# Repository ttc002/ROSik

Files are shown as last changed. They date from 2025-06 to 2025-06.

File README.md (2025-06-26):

# ROSiK  
**Robot Operating System — interactive Kit**  

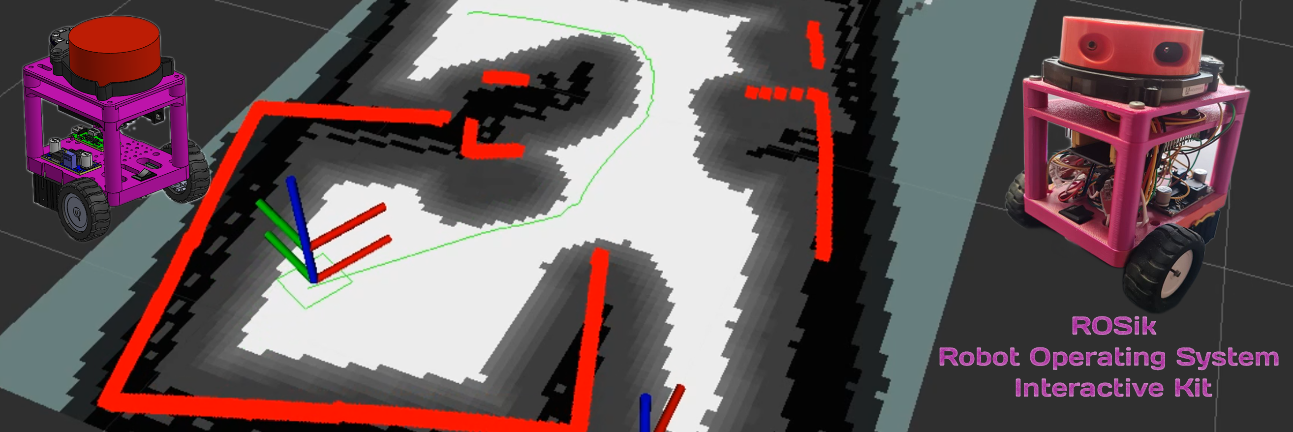
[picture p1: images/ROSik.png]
Робот ROSik


Мини-робот на **ESP32 Wroom-32 + ROS 2**, который:
* транслирует одометрию и лидар по Wi-Fi через WebSocket-мост;
* строит карты и локализуется (`slam_toolbox`);
* планирует путь (`nav2`);
* легко расширяется модулями — камера, IMU, динамик, адресные LED, OLED-дисплей.

Работает **на любой машине**: чистая Ubuntu 24.04, WSL 2 под Windows или виртуалка — нужен лишь Wi-Fi.

Инструкция по установке [Ubuntu](https://stepik.org/lesson/1505338/step/1?unit=1525484), [WSL](https://stepik.org/lesson/1505339/step/4?unit=1525485), а также  [запуску графический приложений (RVIZ)](https://stepik.org/lesson/1505339/step/5?unit=1525485).

---

## 📑 Содержание
1. [Аппаратная часть (BOM)](#аппаратная-часть-bom)  
2. [Электрическая схема](#электрическая-схема)  
3. [3D-модели и сборка](#3d-модели-и-сборка)  
4. [Прошивка ESP32](#прошивка-esp32)
5. [Настройка PID и тестирование](#настройка-pid)
6. [Установка нод в ROS2](#установка-по-на-пк)  
7. [Запуск ROS 2-нод](#запуск-ros-2-нод)  
8. [Контакты](#контакты)

## 🛒<a id="аппаратная-часть-bom">Аппаратная часть (BOM)</a>

* | 1 | **ESP32 Wroom-32 DevKit**         | https://aliexpress.ru/item/1005006697750568.html
* | 2 | DC-мотор N20 60 RPM + энкодер     | https://aliexpress.ru/item/1005007145668771.html
* | 3 | Драйвер моторов ZK-5AD            | https://aliexpress.ru/item/1005005798367960.html
* | 4 | Лидар                             | https://aliexpress.ru/item/1005008371059417.html
* | 5 | Аккумулятор 18650 × 2 + держатель | https://aliexpress.ru/item/1005005447141518.html
* | 6 | Понижающий DC-DC                  | https://aliexpress.ru/item/32896699470.html
* | 7 | Переключатель питания             | https://aliexpress.ru/item/4000973563250.html
* | 8 | Type-C зарядка  2S 1A             | https://aliexpress.ru/item/1005006628986640.html

---

## 🔌 <a id="электрическая-схема">Электрическая схема</a>

Файл CorelDraw **`/Scheme/ROSik_scheme.cdr`**  
а также PNG **`/Scheme/scheme.png`**. 
В схеме показаны соединения питания (8,4 V → 5 V), сигнальные линии к драйверу моторов, энкодерам, лидару (UART)  
схема Fritzing **`/Scheme/MAIN.png`** с добавлением дисплеев и динамика.
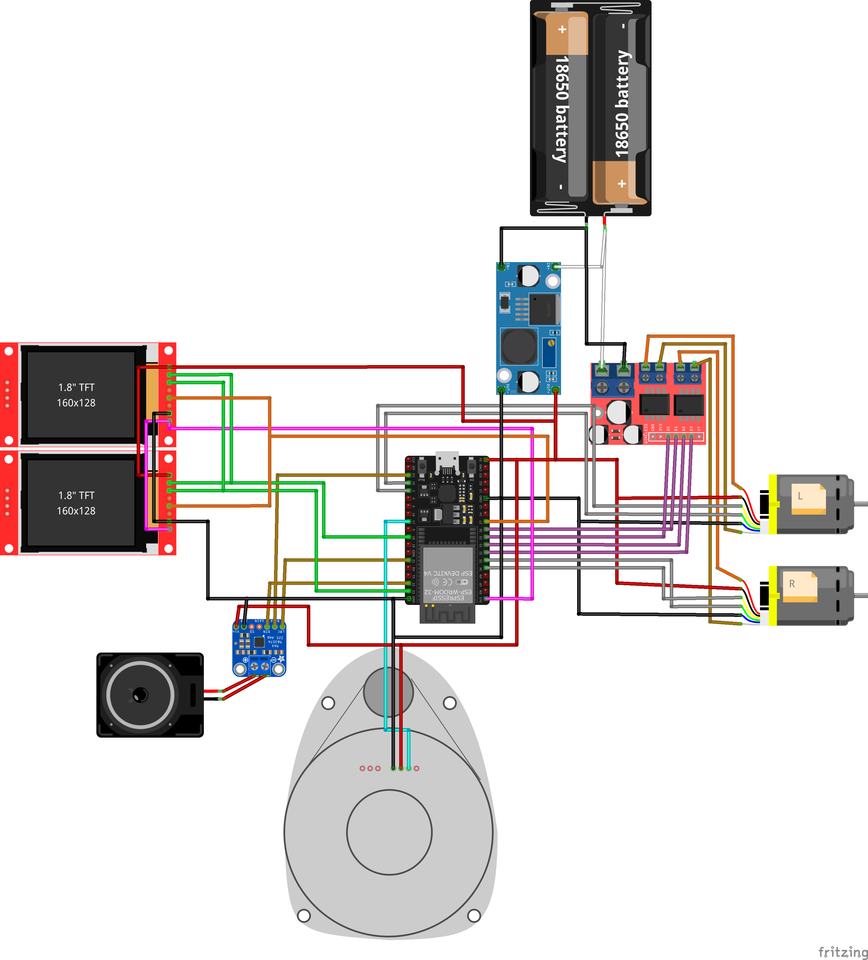
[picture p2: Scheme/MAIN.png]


---

## 🖨 <a id="3d-модели-и-сборка">3D-модели и сборка</a>

Каталог **`/3D`** содержит файлы SolidWorks (`.SLDPRT/.SLDASM`) и готовые `.STL` для печати.

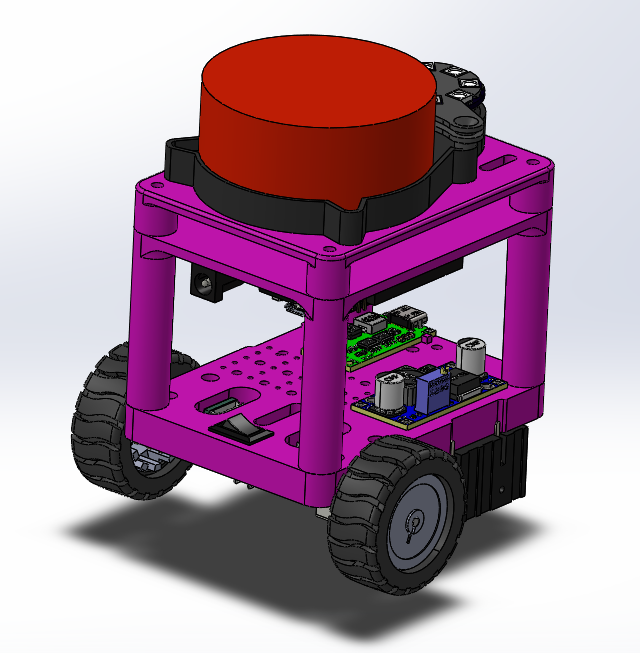
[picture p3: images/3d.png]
3D-модель

* | `00 - WheelLayer.*`    | Нижняя плита с моторами 
* | `01 - LidarLayer.*`    | Верхняя плита под лидар 
* | `10 - ESPLayer.*`      | Средняя плита под ESP32 и драйвер 
* | `Bracket.* / Holder.*` | Крепёж моторов, DC-DC и т.п. 
* | `RosikAssambl.SLDASM`  | Полная сборка 
* | `STL/`                 | Файлы для печати (0,2 мм, PLA) 
* | `ROSik.png`            | Рендер итогового вида 

Собирать снизу → вверх, фиксируя слои стойками M3 × 20 мм. Проводку прячем во внутреннем объеме робота.

---

## 🔥<a id="прошивка-esp32"> Прошивка ESP32 </a>

### Требуемые библиотеки (Arduino IDE)

* Скопируйте ZIP-файлы из `/esp32_libraries/` в `Documents/Arduino/libraries`  
* Добавьте плату ESP32: `File → Preferences → Additional URL` → `https://raw.githubusercontent.com/espressif/arduino-esp32/gh-pages/package_esp32_index.json`
* Через Board Manager добавьте ESP32

### Шаги прошивки

1. Откройте **`/esp32_firmware/esp32_firmware.ino`** в Arduino IDE.  
2. Измените SSID и пароль Wi-Fi сети.  
3. Порт: `Tools → Port → /dev/ttyUSB?` (или COM\*)
4. Плата: `ESP32 Wroom DA Module`
5. Загрузка `Ctrl + U`.  
6. После рестарта ESP32 печатает IP-адрес в Serial Monitor. Скорость: `115200 baud`.

> Прошивка для ESP32_cam (`/esp32_cam/firmware/firmware.ino`) 

---

## <a id="настройка-pid">Настройка PID и тестирование робота</a>

### Утилита позволив вам подобрать коэффициенты PID - регулятора и приверить его работу
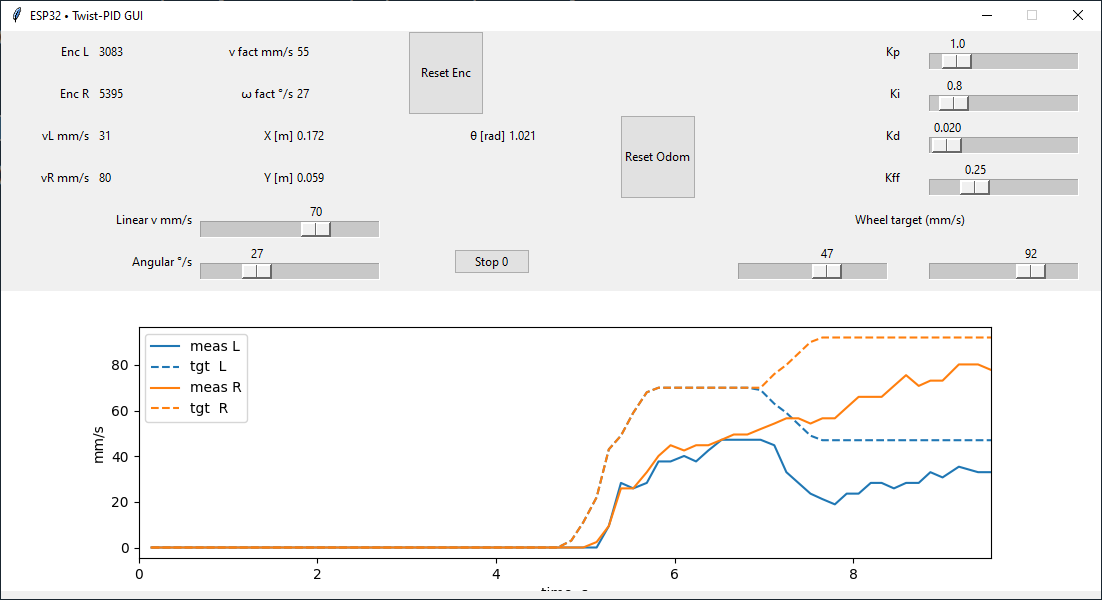
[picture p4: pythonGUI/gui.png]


* Измените IP адрес
* Проверьте работу одометрии и управления роботом
* Подберите коэффициенты и измените их в прошивке робота

---

## 🐧 Установка Ноды в ROS2

```bash
# 1. Создаём рабочую директорию
mkdir -p ~/ros2_ws/src && cd ~/ros2_ws/src

# 2. Копируем esp32_bridge в ~/ros2_ws/src

# 3. Сборка
cd ~/ros2_ws
colcon build
source install/setup.bash

````

* Все конфиги лежат в директории `esp32_bridge\config`. При запуске исправить пути к конфигам на актуальные
* протестировано на **ROS 2 Jazzy** (Ubuntu 24.04)
* в **WSL 2** нужен X-server (XLaunch) для RViz 2

---

## 🚀<a id="запуск-ros-2-нод"> Запуск ROS 2-нод </a>

| Шаг | Команда | Описание |
| --- | --- | --- |
| 1 | `ros2 run esp32_bridge esp32_bridge --ros-args -p host:=<IP_ESP32> ` | WebSocket-мост |
| 2 | `rviz2`  → `File → Open Config` → `config/rviz/rosik.rviz` | Визуализация данных |
| 3 | `ros2 launch slam_toolbox online_sync_launch.py slam_params_file:=~/ros2_ws/src/esp32_bridge/config/slam_param.yaml` | Онлайн SLAM |
| 4 | `ros2 run teleop_twist_keyboard teleop_twist_keyboard` | Телеуправление |
| 5 | `ros2 service call /slam_toolbox/serialize_map slam_toolbox/srv/SerializePoseGraph "{filename: '~/ros2_ws/maps/my_map'}"` | Сохранить карту |
| 6 | `ros2 launch slam_toolbox localization_launch.py slam_params_file:=~/ros2_ws/src/esp32_bridge/config/slam_localization.yaml`| Локализация |
| 7 | `ros2 launch nav2_bringup navigation_launch.py params_file:=~/ros2_ws/src/esp32_bridge/config/nav_param.yaml` | Навигация `nav2` |

> **WSL 2**: перед запуском RViz 2<br>
> `export DISPLAY=$(ip route | awk '/default/ {print $3}'):0.0` или
> `export DISPLAY=xxx.xxx.xxx.xxx:0.0`

Настройки RVIZ в файле `esp32_bridge/config/rviz.rviz`
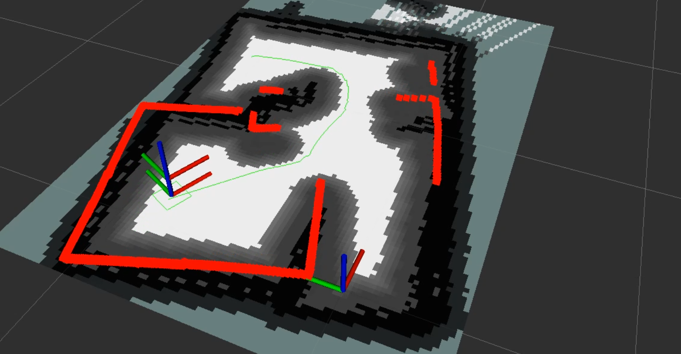
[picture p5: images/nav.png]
Работа навигации


## GIF - демонстрация движения в автономном режиме
Работа навигации

## Дисплей
`ros2 run image_stream send_image --ros-args -p host:=<YOUR_ESP_IP>` - отправляет данные по socket на дисплей из /image_raw. Прошивка MAIN.ino

`ros2 run image_stream read_image --ros-args -p video_path:=<VIDEO_PATH>` - отправляет данные в топик /image_rgb

## Динамик 
`ros2 run esp_miniBot send_music --ros-args -p host:=<YOUR_ESP_IP>` - отправляет музыку из топика /audio_bytes

`ros2 run esp_miniBot read_mp3 --ros-args -p folder:=<YOUR_FOLDER>` - чтение mp3 из папки

`ros2 run esp_miniBot speaker` - создание вируального динамика, и чтение из него в топик

---
<a id="контакты">Контакты</a>
* Telegram: **[@burmistrov\_robotics](https://t.me/burmistrov_robotics)**  **[@petrArchLinux](https://t.me/petrArchLinux)**
* Stepik- Народный курс по ROS2: [https://stepik.org/course/221157](https://stepik.org/course/221157)

---

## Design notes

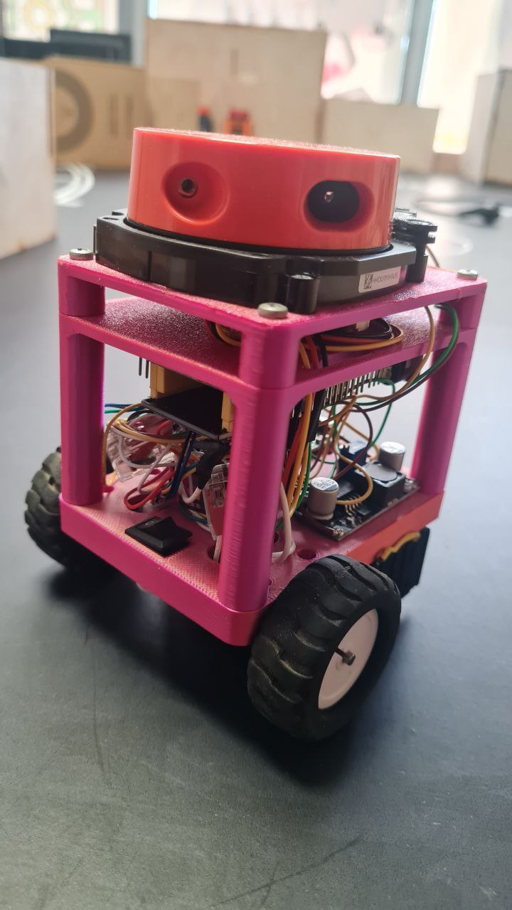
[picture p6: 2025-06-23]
images/photo.jpg

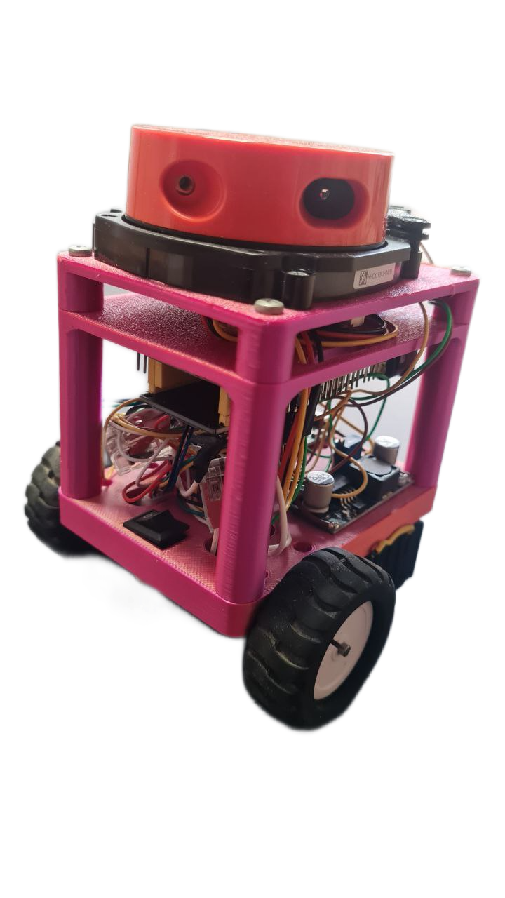
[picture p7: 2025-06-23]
images/photo.png

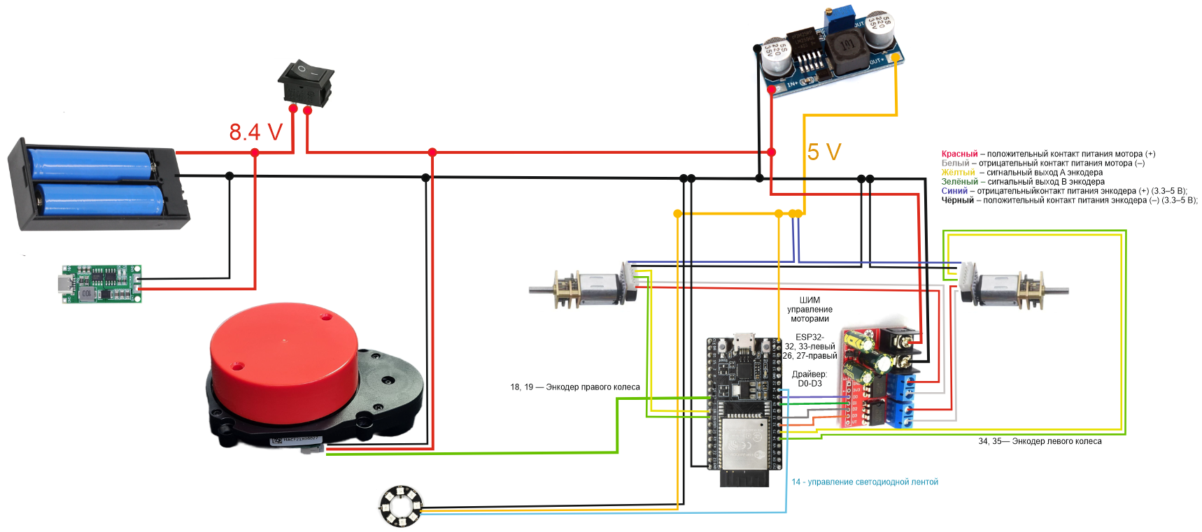
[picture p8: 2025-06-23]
Scheme/scheme.png

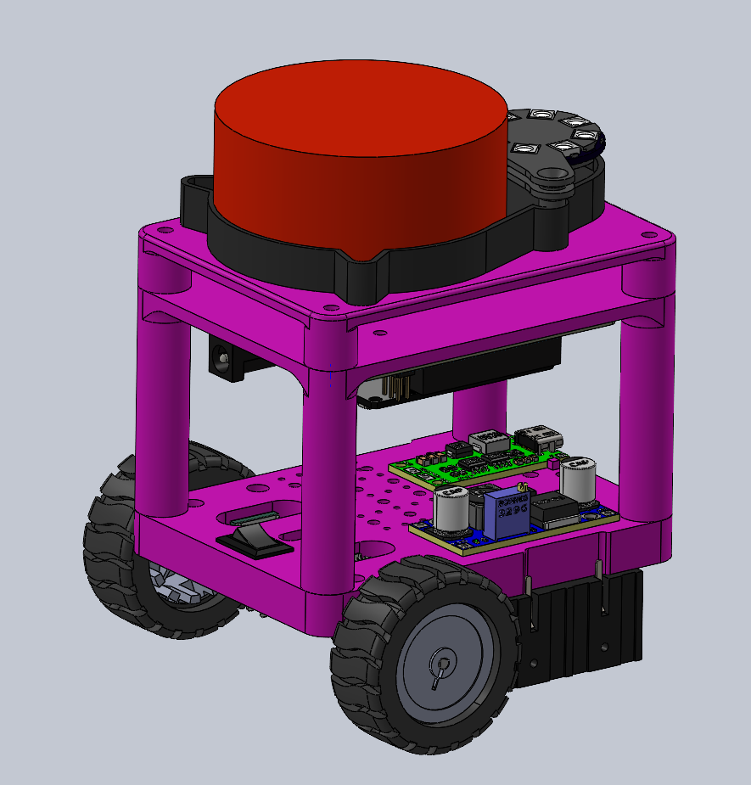
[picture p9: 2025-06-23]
3D/ROSik.png

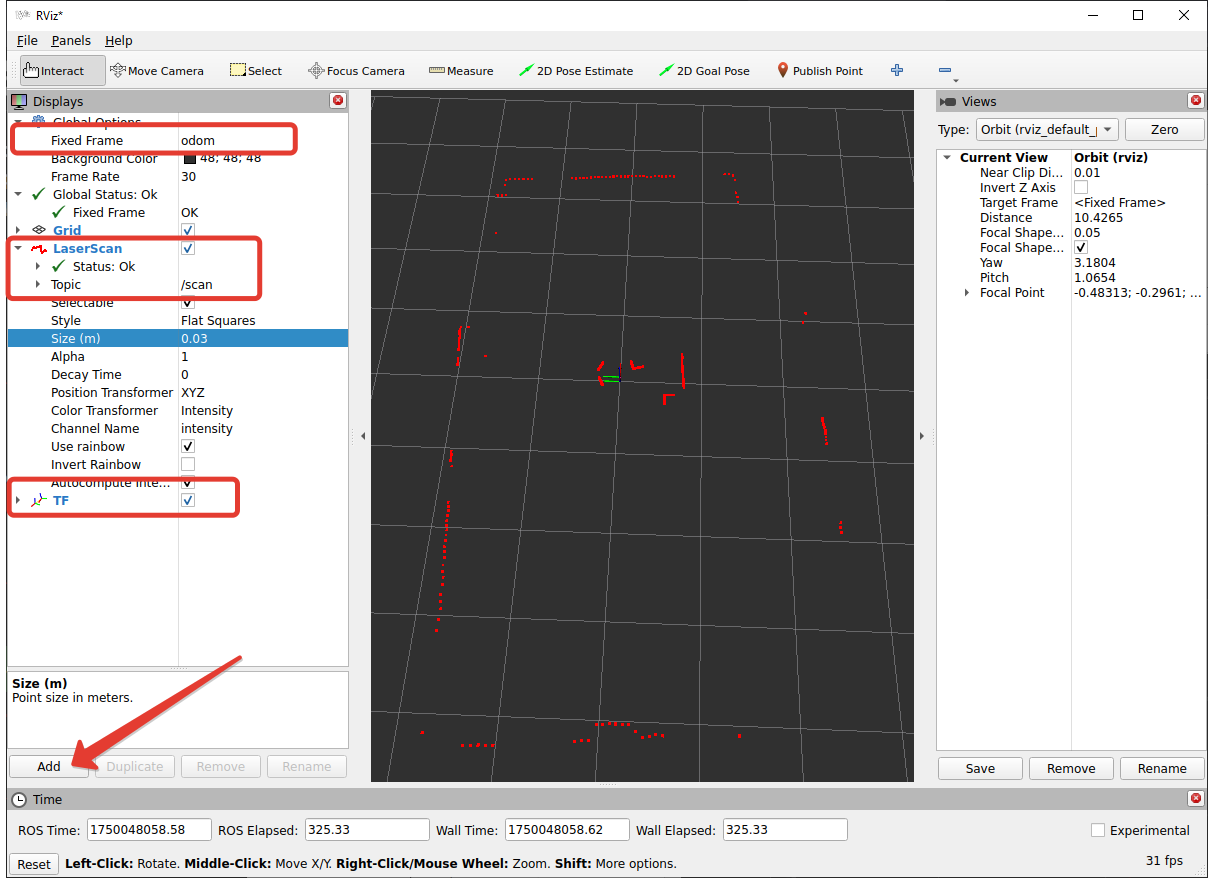
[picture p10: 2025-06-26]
code/rviz2.png

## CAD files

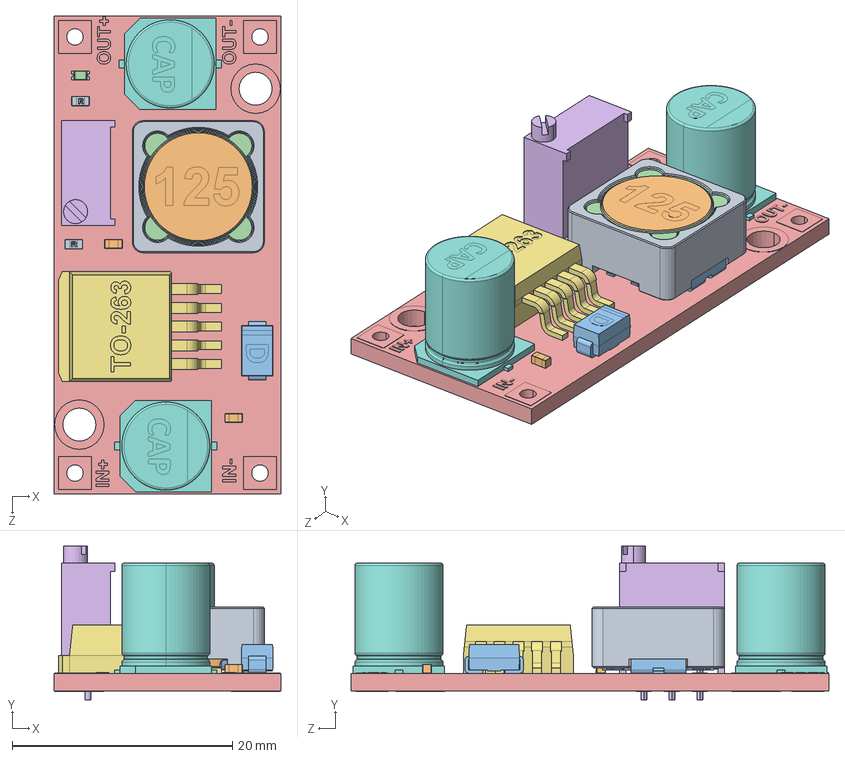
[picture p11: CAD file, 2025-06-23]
3D/DC_DC.SLDASM
20.6 x 14.0 x 43.4 mm
001^CDRH125_HW-411.STEP
002^CDRH125_HW-411.STEP
005^CDRH125_HW-411.STEP x 2
003^CDRH125_HW-411.STEP
Board^HW-411.STEP
RES_3296W^HW-411.STEP
TO-263-5^HW-411.STEP
CAP_SMD_AL_08.0x10.0^HW-411.STEP x 2
RES_SMD_0603^HW-411.STEP x 2
CAP_SMD_0603_H0.50^HW-411.STEP x 2
Diode_DO214AC(SMA)^HW-411.STEP
LED_0603_Green^HW-411.STEP

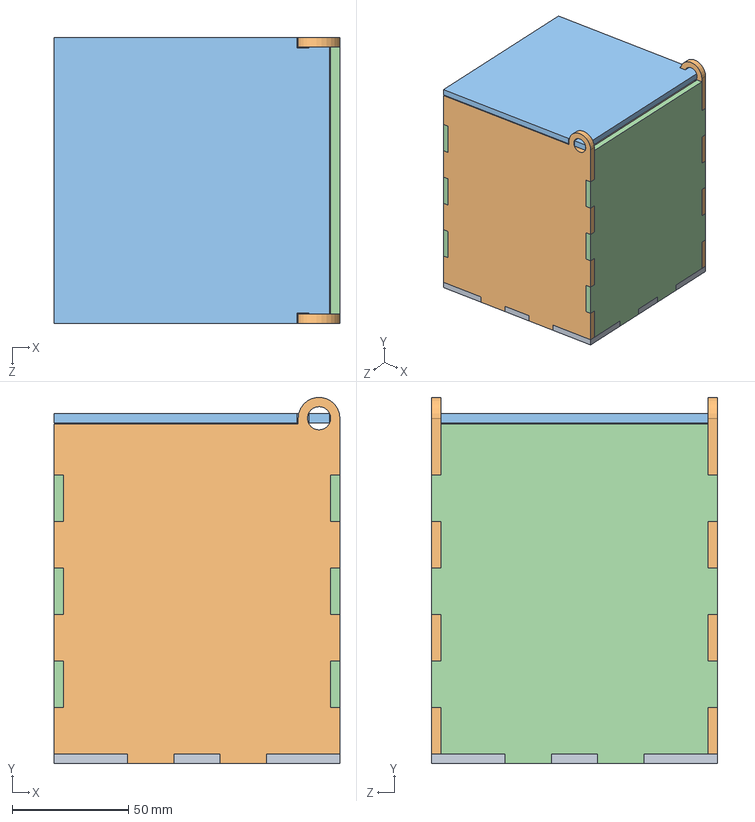
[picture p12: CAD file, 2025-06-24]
3D/ROSik_BOX/Сборка122.SLDASM
123.0 x 157.4 x 123.0 mm
Дно
БокСОтв x 2
Крышка
ПередСтенка x 2

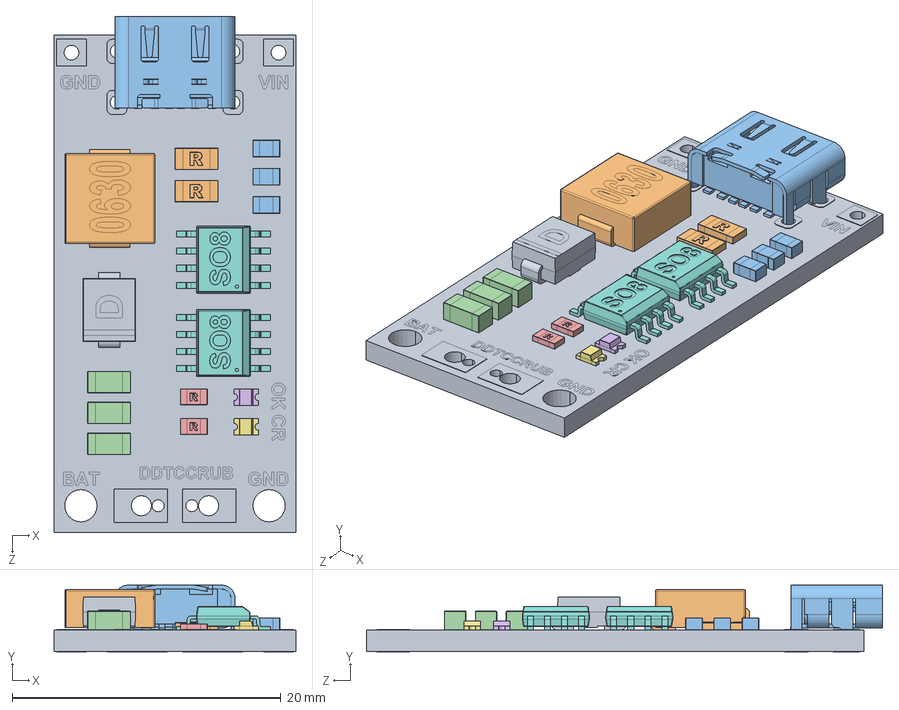
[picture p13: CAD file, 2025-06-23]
3D/Type_cCharger.SLDASM
18.0 x 4.98 x 38.4 mm
Board^DDTCCRUB CN330X.STEP
RES_SMD_1206^DDTCCRUB CN330X.STEP x 2
CAP_SMD_0805_H0.9^DDTCCRUB CN330X.STEP x 3
CAP_SMD_1206_H1.4^DDTCCRUB CN330X.STEP x 3
RES_SMD_0805^DDTCCRUB CN330X.STEP x 2
LED_0805_Green^DDTCCRUB CN330X.STEP
LED_0805_Red^DDTCCRUB CN330X.STEP
SO8^DDTCCRUB CN330X.STEP x 2
Diode_DO214AA(SMB)^DDTCCRUB CN330X.STEP
Inductor_SMD_AMPLF_0630^DDTCCRUB CN330X.STEP
USB_Type-C_Female_6pin^DDTCCRUB CN330X.STEP

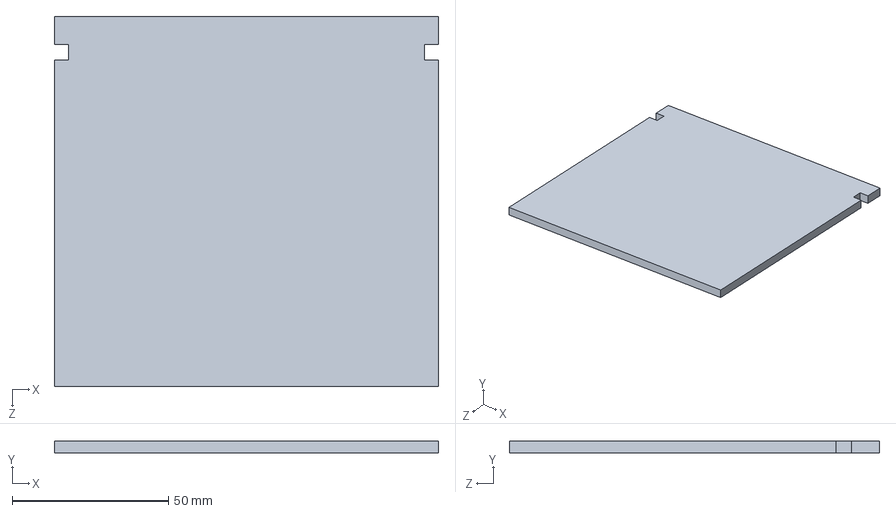
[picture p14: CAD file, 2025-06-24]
3D/ROSik_BOX/Крышка.SLDPRT
123.0 x 4.00 x 118.5 mm

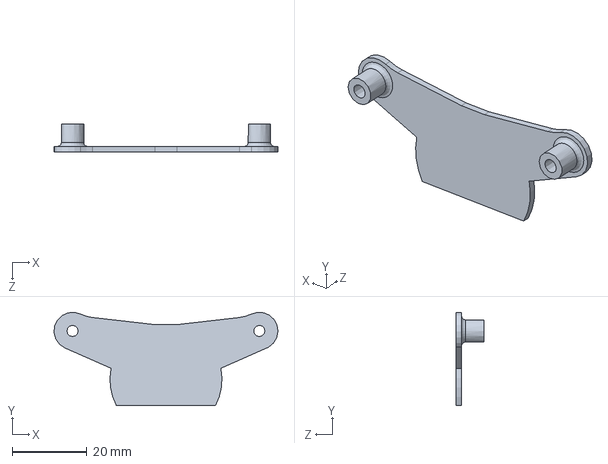
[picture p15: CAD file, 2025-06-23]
3D/11 - 8ledHolderBottom.SLDPRT
60.0 x 25.0 x 7.50 mm

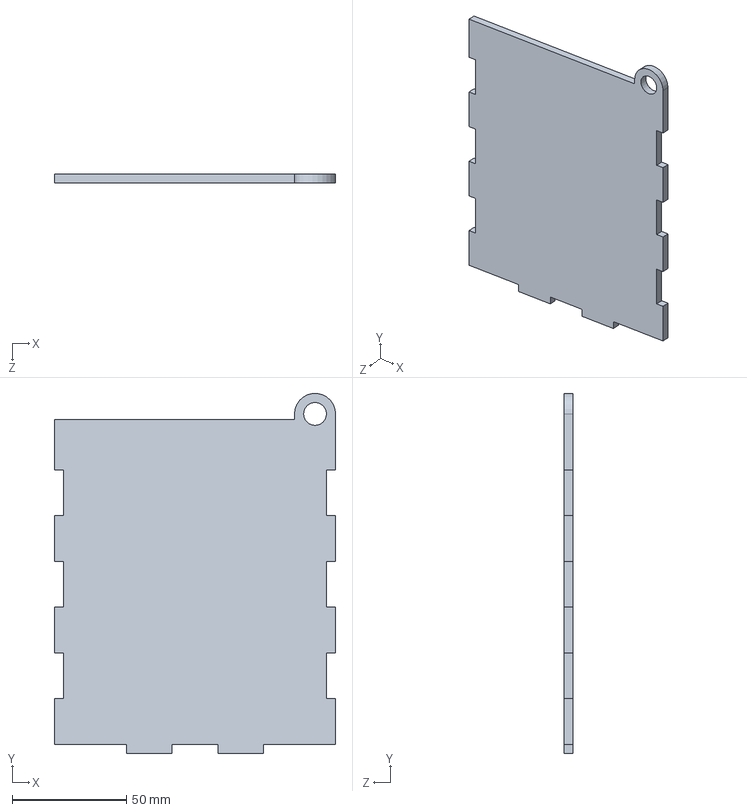
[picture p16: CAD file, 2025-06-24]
3D/ROSik_BOX/БокСОтв.SLDPRT
123.0 x 157.4 x 4.00 mm

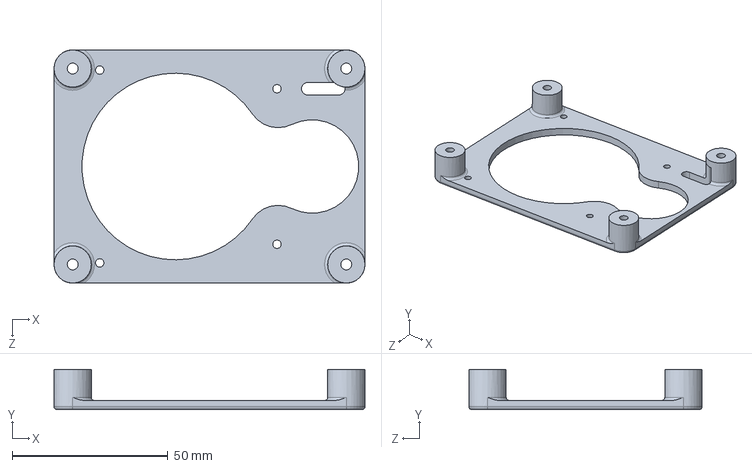
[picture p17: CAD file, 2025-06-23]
3D/01 - LidarLayer.SLDPRT
100.0 x 13.0 x 75.0 mm

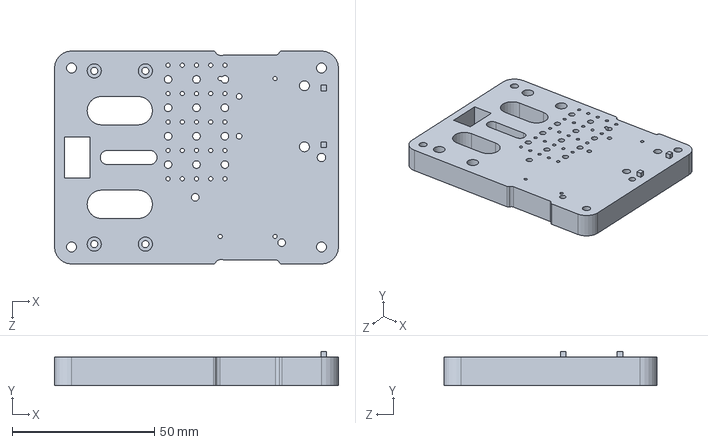
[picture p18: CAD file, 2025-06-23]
3D/00 - WheelLayer.SLDPRT
100.0 x 12.0 x 75.0 mm

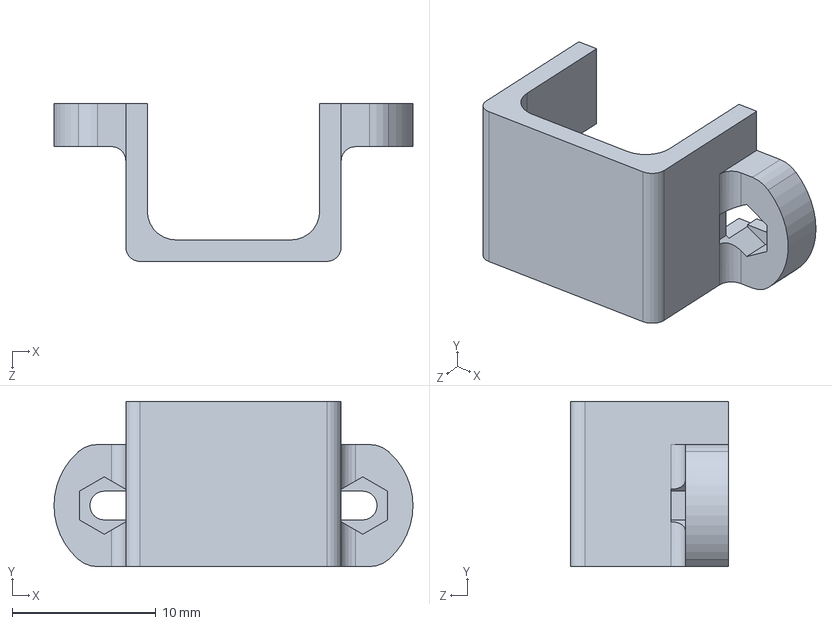
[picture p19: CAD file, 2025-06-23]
3D/Bracket.SLDPRT
25.0 x 11.5 x 11.0 mm

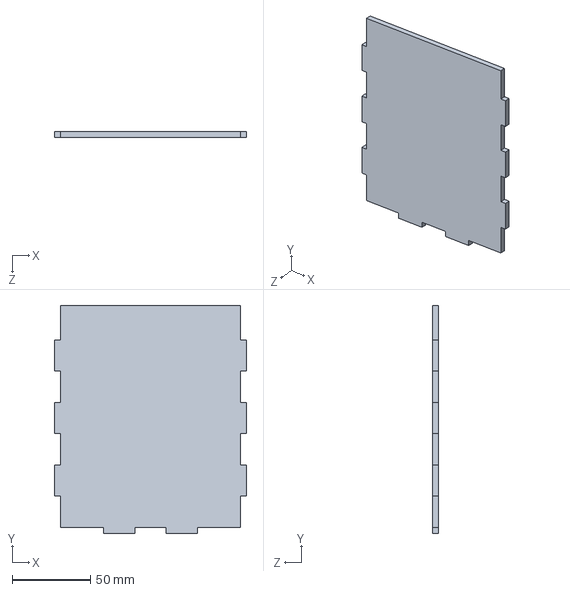
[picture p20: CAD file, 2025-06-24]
3D/ROSik_BOX/ПередСтенка.SLDPRT
123.0 x 146.0 x 4.00 mm

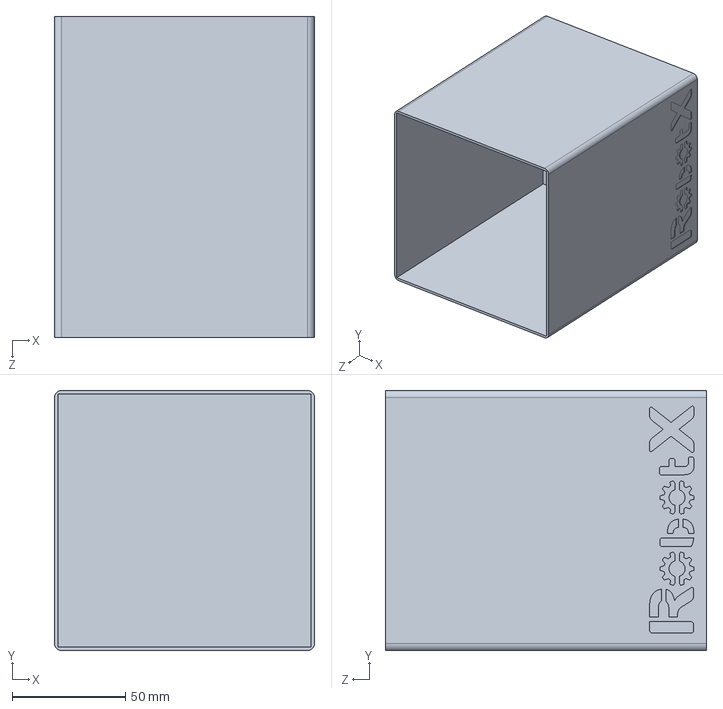
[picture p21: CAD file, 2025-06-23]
3D/ROSik_BOX/3D_printBox.SLDPRT
115.0 x 115.0 x 142.0 mm

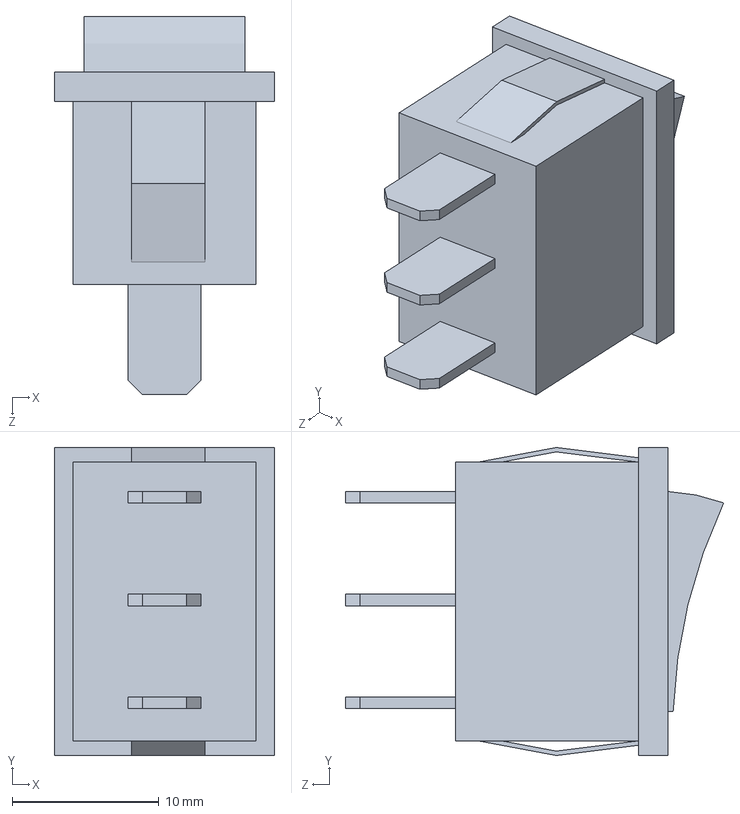
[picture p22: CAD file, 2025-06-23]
3D/Switch.SLDPRT
15.0 x 21.0 x 25.8 mm

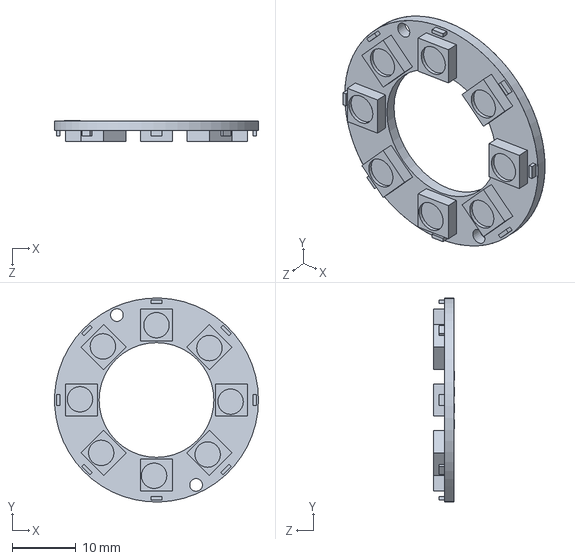
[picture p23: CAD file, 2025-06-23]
3D/WCMCU-2812B-8-32mm.SLDPRT
32.0 x 32.0 x 3.30 mm

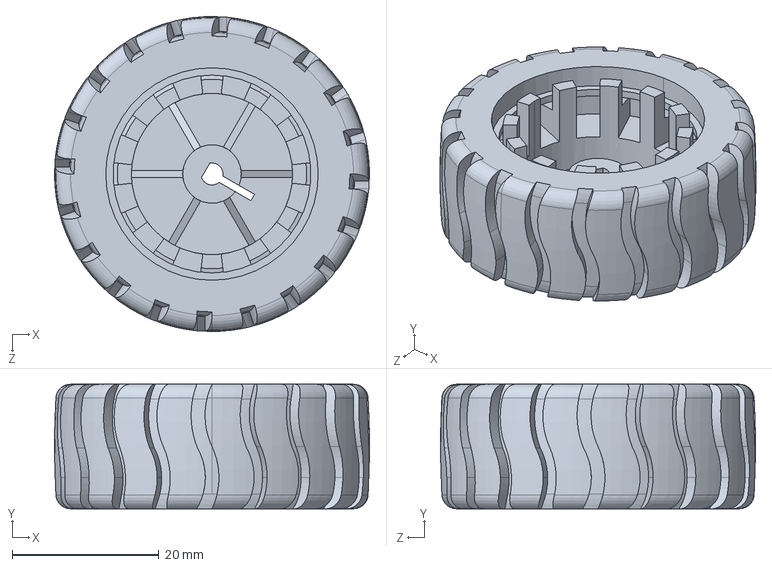
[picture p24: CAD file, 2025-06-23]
3D/Wheel.SLDPRT
43.0 x 17.0 x 43.0 mm

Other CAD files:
3D/ROSik_BOX/Дно.SLDPRT
3D/Holder.SLDPRT
3D/Braket motor N20 60RPM.SLDPRT
3D/Velg + Ban.SLDPRT
3D/10 - ESPLayer.SLDPRT
3D/11 - 8ledHolderTop.SLDPRT
3D/18650older/KLS5-18650-002-D.SLDASM
3D/18650older/KLS5-18650-002-D.STEP
3D/18650older/KLS5-18650-002-D_Me.SLDPRT
3D/18650older/KLS5-18650-002-D_Plastic.SLDPRT
3D/MINI SWITCH.SLDPRT
3D/STL/00 - WheelLayer.STL
3D/STL/01 - LidarLayer.STL
3D/STL/10 - ESPLayer.STL
3D/ydlidar x4.SLDPRT

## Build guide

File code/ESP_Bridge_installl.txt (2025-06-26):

Полная пошаговая инструкция: пакет esp32_bridge
Установите ROS2: Ссылка
Добейтесь запуска RVIZ2 (настройка для WSL). rviz2
pip3 install aiohttp  --break-system-packages

pip3 install requests --break-system-packages

pip3 install matplotlib --break-system-packages

Шаг 1. Рабочее пространство
cd ~
mkdir -p ros2_ws/src
cd ros2_ws/src
Шаг 2. Активируем окружение ROS 2
source /opt/ros/jazzy/setup.bash     # добавьте в ~/.bashrc на будущее

echo "source /opt/ros/jazzy/setup.bash" >> ~/.bashrc
Шаг 3. Создаём Python-пакет
cd ~/ros2_ws/src
ros2 pkg create --build-type ament_python esp32_bridge
Структура:

esp32_bridge/
├── esp32_bridge/        # здесь будет нода
│   └── __init__.py
├── package.xml
├── setup.cfg
├── setup.py
└── resource/…
Шаг 4. Добавляем ноду
cd ~/ros2_ws/src/esp32_bridge
touch esp32_bridge/bridge_node.py
chmod +x esp32_bridge/bridge_node.py
Откройте nano ~/ros2_ws/src/esp32_bridge/esp32_bridge/bridge_node.py и вставьте код:

#!/usr/bin/env python3
# -*- coding: utf-8 -*-
"""
esp_bridge.py  •  LiDAR (+ yaw / mirror / static TF)  •  /cmd_vel → ESP  •  /odom  (ROS 2 Jazzy)

* WebSocket-скан от ESP32  →  /scan   (sensor_msgs/LaserScan)
* REST-команда /setSpeed   ← /cmd_vel (geometry_msgs/Twist)
* HTTP /state → /odom + TF (nav_msgs/Odometry + динамический odom→base_link)

Дополнительные параметры конфигурируют датчик:

  lidar_yaw_deg     (double, ° CW) – повернуть облако
  lidar_mirror      (bool)         – отразить (лево↔право)
  lidar_xyz         (double[3])    – смещение лидара в базе  [м]
  lidar_rpy_deg     (double[3])    – ориентация лидара       [° R P Y]

При старте узел публикует *статический* трансформ base_link→laser,
поэтому RViz/ Nav2 сразу видят полную цепочку `odom → base_link → laser`.
"""

import asyncio
import math
import struct
import threading
import socket
import urllib.parse
import requests
import rclpy
from rclpy.node import Node
from sensor_msgs.msg import LaserScan
from geometry_msgs.msg import Twist, Quaternion
from nav_msgs.msg import Odometry
from tf2_ros import (
    TransformBroadcaster,
    StaticTransformBroadcaster,
    TransformStamped,
)
import websockets

# ――― константы LDS пакетов ―――――――――――――――――――――――――――――――――――――――――――――――
FRAME_FMT = "<HHHHHHHHHH"          # 20 B – угол начала, угол конца, 8×дистанция
FRAME_SZ = 20
CRC_SZ = 2
MAX_PKTS = 64                      # макс. пакетов на оборот
MAX_SIZE = MAX_PKTS * FRAME_SZ + CRC_SZ

BASE_MM = 96.0                     # база робота (колёс), мм

def crc16(buf: bytes, crc: int = 0xFFFF) -> int:
    """Modbus-совместимый CRC-16"""
    for b in buf:
        crc ^= b
        for _ in range(8):
            crc = (crc >> 1) ^ (0xA001 if crc & 1 else 0)
    return crc & 0xFFFF

def q_yaw(yaw: float) -> Quaternion:
    """Quaternion из Yaw (рад)"""
    q = Quaternion()
    q.z = math.sin(yaw * 0.5)
    q.w = math.cos(yaw * 0.5)
    return q

def rpy_to_quat(roll: float, pitch: float, yaw: float) -> Quaternion:
    """RPY (рад) → Quaternion"""
    cy, sy = math.cos(yaw / 2), math.sin(yaw / 2)
    cp, sp = math.cos(pitch / 2), math.sin(pitch / 2)
    cr, sr = math.cos(roll / 2), math.sin(roll / 2)
    q = Quaternion()
    q.w = cr * cp * cy + sr * sp * sy
    q.x = sr * cp * cy - cr * sp * sy
    q.y = cr * sp * cy + sr * cp * sy
    q.z = cr * cp * sy - sr * sp * cy
    return q

# ―――― основной узел ―――――――――――――――――――――――――――――――――――――――――――――――――――
class ESPBridge(Node):
    def __init__(self) -> None:
        super().__init__("esp_bridge")

        # ── параметры подключения ──────────────────────────────────
        self.declare_parameter("host", "192.168.0.105")
        self.declare_parameter("ws_port", 80)
        self.declare_parameter("ws_path", "/ws")

        # ── имена фреймов и диапазон LiDAR-a ───────────────────────
        self.declare_parameter("frame_id", "laser")
        self.declare_parameter("odom_frame", "odom")
        self.declare_parameter("base_frame", "base_link")
        self.declare_parameter("range_min", 0.05)
        self.declare_parameter("range_max", 2.0)

        # ── настройка ориентации LiDAR-а ───────────────────────────
        self.declare_parameter("lidar_yaw_deg", 180.0)        # сдвиг облака CW
        self.declare_parameter("lidar_mirror", True)          # зеркально (True/False)
        self.declare_parameter("lidar_xyz", [0.0, 0.0, 0.10]) # положение на раме
        self.declare_parameter("lidar_rpy_deg", [0.0, 0.0, 0.0])  # ориентация

        # ── формируем URL WebSocket ――
        host = self.get_parameter("host").value
        port = self.get_parameter("ws_port").value
        path = self.get_parameter("ws_path").value
        self.ws_url = f"ws://{host}:{port}{path}"

        # ── ROS паблишеры/сабскрайберы ────────────────────────────
        self.scan_pub = self.create_publisher(LaserScan, "/scan", 10)
        self.odom_pub = self.create_publisher(Odometry, "/odom", 10)
        self.create_subscription(Twist, "/cmd_vel", self.cmd_cb, 10)

        # динамический TF (odom→base_link) + статический (base_link→laser)
        self.tf_br = TransformBroadcaster(self)
        self.static_br = StaticTransformBroadcaster(self)
        self._publish_static_tf()

        # ― запускаем отдельный event-loop для WebSocket (лидар) ―
        self.ws_loop = asyncio.new_event_loop()
        threading.Thread(
            target=self._run_ws_loop, args=(self.ws_loop,), daemon=True
        ).start()

        # ― периодический HTTP-опрос /state ―
        self.create_timer(0.10, self.poll_state)

        self.get_logger().info(f"LiDAR WebSocket →  {self.ws_url}")

    # =============================================================
    #                 статический TF  base_link → laser
    # =============================================================
    def _publish_static_tf(self) -> None:
        xyz = self.get_parameter("lidar_xyz").value
        rpy_deg = self.get_parameter("lidar_rpy_deg").value

        roll, pitch, yaw = [math.radians(a) for a in rpy_deg]
        q = rpy_to_quat(roll, pitch, yaw)

        tf = TransformStamped()
        tf.header.stamp = self.get_clock().now().to_msg()
        tf.header.frame_id = self.get_parameter("base_frame").value
        tf.child_frame_id = self.get_parameter("frame_id").value
        tf.transform.translation.x = float(xyz[0])
        tf.transform.translation.y = float(xyz[1])
        tf.transform.translation.z = float(xyz[2])
        tf.transform.rotation = q

        # latched – публикуем один раз
        self.static_br.sendTransform(tf)
        self.get_logger().info("Published static TF base_link → laser")

        tf = TransformStamped()
        tf.header.stamp = self.get_clock().now().to_msg()
        tf.header.frame_id = "map"
        tf.child_frame_id = "odom"
        tf.transform.translation.x = 0.0
        tf.transform.translation.y = 0.0
        tf.transform.translation.z = 0.0
        tf.transform.rotation = rpy_to_quat(0.0,0.0,0.0)

        # latched – публикуем один раз
        self.static_br.sendTransform(tf)
        self.get_logger().info("Published static TF map → odom")

    # =============================================================
    #                    WebSocket (LiDAR поток)
    # =============================================================
    def _run_ws_loop(self, loop: asyncio.AbstractEventLoop) -> None:
        asyncio.set_event_loop(loop)
        loop.run_until_complete(self.ws_task())

    async def ws_task(self) -> None:
        while rclpy.ok():
            try:
                async with websockets.connect(
                    self.ws_url, max_size=None, ping_interval=None
                ) as ws:
                    # disable Nagle
                    sock: socket.socket = ws.transport.get_extra_info("socket")
                    if sock:
                        sock.setsockopt(socket.IPPROTO_TCP, socket.TCP_NODELAY, 1)
                    self.get_logger().info("WS connected")

                    while rclpy.ok():
                        buf = await ws.recv()
                        if not isinstance(buf, (bytes, bytearray)):
                            continue
                        if not (FRAME_SZ + CRC_SZ <= len(buf) <= MAX_SIZE):
                            continue
                        if crc16(buf[:-2]) != int.from_bytes(buf[-2:], "little"):
                            continue
                        self.publish_scan(buf[:-2])

            except Exception as e:
                self.get_logger().warn(f"WS error: {e}")
                await asyncio.sleep(1.0)

    # =============================================================
    #               /cmd_vel  →  HTTP /setSpeed
    # =============================================================
    def cmd_cb(self, msg: Twist) -> None:
        v_mm = msg.linear.x * 1000.0
        w = msg.angular.z
        left = int(v_mm - w * BASE_MM / 2.0)
        right = int(v_mm + w * BASE_MM / 2.0)

        host = self.get_parameter("host").value
        qs = "/setSpeed?" + urllib.parse.urlencode({"l": left, "r": right})
        try:
            requests.get(f"http://{host}{qs}", timeout=0.15)
        except Exception as e:
            self.get_logger().warn(f"/setSpeed fail: {e}")

    # =============================================================
    #               преобразуем пакеты LDS → LaserScan
    # =============================================================
    def publish_scan(self, raw: bytes) -> None:
        pkt_cnt = len(raw) // FRAME_SZ
        if pkt_cnt < 38:  # < ~270°
            return

        ang, rng, inten = [], [], []
        prev = None
        off = 0.0

        for i in range(pkt_cnt):
            s, e, *dist = struct.unpack_from(FRAME_FMT, raw, i * FRAME_SZ)
            s /= 100.0
            e /= 100.0
            if e < s:
                e += 360.0

            for j, d in enumerate(dist):
                a = s + (e - s) * j / 7
                if prev is not None and a + off < prev - 300:
                    off += 360.0
                a += off
                prev = a

                ang.append(a)
                rng.append(d / 1000.0 if d else float("inf"))
                inten.append(1.0 if d else 0.0)

        # зеркалим?
        if self.get_parameter("lidar_mirror").value:
            ang.reverse()
            rng.reverse()
            inten.reverse()
            ang = [-a for a in ang]

        # добавляем поворот
        yaw_deg = self.get_parameter("lidar_yaw_deg").value
        if yaw_deg:
            ang = [a + yaw_deg for a in ang]

        # нормализуем, чтобы начало ≈ −π
        if ang[0] > 180.0:
            ang = [a - 360.0 for a in ang]

        rad = [math.radians(a) for a in ang]

        scan = LaserScan()
        scan.header.stamp = self.get_clock().now().to_msg()
        scan.header.frame_id = self.get_parameter("frame_id").value
        scan.angle_min = rad[0]
        scan.angle_max = rad[-1]
        scan.angle_increment = (rad[-1] - rad[0]) / (len(rad) - 1)
        scan.range_min = self.get_parameter("range_min").value
        scan.range_max = self.get_parameter("range_max").value
        scan.ranges = rng
        scan.intensities = inten
        self.scan_pub.publish(scan)

    # =============================================================
    #                 HTTP /state → /odom  (+ TF)
    # =============================================================
    def poll_state(self) -> None:
        host = self.get_parameter("host").value
        try:
            js = requests.get(f"http://{host}/state", timeout=0.25).json()
        except Exception:
            return

        x, y, th = js["odom"]["x"], js["odom"]["y"], js["odom"]["th"]

        od = Odometry()
        od.header.stamp = self.get_clock().now().to_msg()
        od.header.frame_id = self.get_parameter("odom_frame").value
        od.child_frame_id = self.get_parameter("base_frame").value
        od.pose.pose.position.x = x
        od.pose.pose.position.y = y
        od.pose.pose.orientation = q_yaw(th)
        od.twist.twist.linear.x = js["speed"]["left"] / 1000.0
        od.twist.twist.angular.z = (
            js["speed"]["right"] - js["speed"]["left"]
        ) / BASE_MM * 1000.0
        self.odom_pub.publish(od)

        tf = TransformStamped()
        tf.header.stamp = od.header.stamp
        tf.header.frame_id = od.header.frame_id
        tf.child_frame_id = od.child_frame_id
        tf.transform.translation.x = x
        tf.transform.translation.y = y
        tf.transform.rotation = od.pose.pose.orientation
        self.tf_br.sendTransform(tf)

# ――― точка входа ――――――――――――――――――――――――――――――――――――――――――――――――――
def main(args=None) -> None:
    rclpy.init(args=args)
    rclpy.spin(ESPBridge())
    rclpy.shutdown()

if __name__ == "__main__":
    main()
Шаг 5. Точка входа
В setup.py найдите / добавьте секцию:

entry_points={
    'console_scripts': [
        'esp32_bridge = esp32_bridge.bridge_node:main',
    ],
},
Шаг 6. Зависимости
В package.xml добавьте в <exec_depend>:

<exec_depend>rclpy</exec_depend>
<exec_depend>geometry_msgs</exec_depend>
<exec_depend>nav_msgs</exec_depend>
<exec_depend>tf2_ros</exec_depend>
Шаг 7. Сборка пакета
cd ~/ros2_ws
colcon build
Шаг 8. Сорсинг окружения
source install/setup.bash
echo "source ~/ros2_ws/install/setup.bash" >> ~/.bashrc
(добавьте в ~/.bashrc, чтобы не повторять).

Шаг 9. Запуск ноды
ros2 run esp32_bridge esp32_bridge
В логе увидите:

[esp32_bridge_node] Started ESP32 bridge for 192.168.0.119  poll=20 ms
Переопределение параметров
ros2 run esp32_bridge esp32_bridge --ros-args -p host:=192.168.0.42 -p wheel_separation:=0.10

ros2 run my_pkg esp_bridge.py \
  --ros-args \
  -p host:=192.168.0.108 \
  -p lidar_xyz:="[0.05,0.00,0.12]" \
  -p lidar_rpy_deg:="[0.0,0.0,180.0]"

Что делает нода
Функция	Реализация
/cmd_vel → /setSpeed	колёсные скорости v_l/r = (v ± ωL/2)·1000 мм/с, HTTP GET
/state → Odometry	берёт odom.{x,y,th} и speed.*, публикует nav_msgs/Odometry
TF	TransformBroadcaster шлёт odom → base_link
Параметры	host, port, poll_period, wheel_separation, frame_id, child_frame_id

Проверяем ручное управление:
ros2 run teleop_twist_keyboard teleop_twist_keyboard

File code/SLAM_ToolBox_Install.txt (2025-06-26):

SLAM Toolbox

sudo apt install ros-jazzy-slam-toolbox ros-jazzy-nav2-bringup ros-jazzy-nav2-common
Если при установке появляется ошибка:
E: Unable to fetch some archives, maybe run apt-get update or try with --fix-missing? 

sudo mkdir -p /etc/apt/keyrings

# Скачиваем свежий ros.asc
sudo curl -sSL https://raw.githubusercontent.com/ros/rosdistro/master/ros.asc -o /etc/apt/keyrings/ros.asc

# Обновляем запись репозитория
echo "deb [arch=amd64 signed-by=/etc/apt/keyrings/ros.asc] \
  http://packages.ros.org/ros2/ubuntu $(lsb_release -cs) main" \
 | sudo tee /etc/apt/sources.list.d/ros2.list

sudo apt update && sudo apt upgrade -y

sudo apt install ros-jazzy-slam-toolbox ros-jazzy-nav2-bringup ros-jazzy-nav2-common
Создайте файл с параметрами:

nano ~/ros2_ws/slam_param.yaml
Содержимое файла:

slam_toolbox:
  ros__parameters:

    # 📡 Названия фреймов и топика лидара
    scan_topic: /scan               # Топик с лазерными сканами
    odom_frame: odom               # Кадр одометрии (обычно "odom")
    map_frame: map                 # Глобальный фрейм карты
    base_frame: base_link          # Фрейм робота (лидара)

    # ⚙️ Режим работы SLAM Toolbox
    mode: mapping                  # Режим построения карты (localization — для использования готовой)

    # 📉 Источники движения
    use_odometry: true             # Использовать одометрию (false, если она сильно врет)
    use_scan_matching: true        # Сопоставление сканов — основа SLAM
    use_scan_barycenter: false     # Использовать геометрический центр скана (обычно false)

    # 🗺️ Параметры построения карты
    resolution: 0.03               # Разрешение карты: размер клетки в метрах
    max_laser_range: 2.5           # Максимальное расстояние луча лидара (должно совпадать с датчиком)
    minimum_time_interval: 0.05    # Минимальное время между обработкой сканов
    transform_publish_period: 0.05 # Как часто публиковать transform map -> odom

    # 🧷 Условия добавления новых узлов (ключевых фреймов)
    minimum_travel_distance: 0.1          # Минимальное смещение робота (м), чтобы добавить узел
    minimum_travel_heading: 0.2           # Минимальный поворот (рад), чтобы добавить узел
    temporal_update_distance: 0.0         # [Отключено] автообновление по пройденному расстоянию
    temporal_update_angle: 0.0            # [Отключено] автообновление по углу

    # 🔁 Частота обновления карты и графа
    occupancy_map_update_frequency: 1.0   # Частота обновления карты (Гц)
    optimization_frequency: 1.0           # Частота оптимизации графа (Гц)
    optimizer_iterations: 10              # Кол-во итераций оптимизатора за проход

    # 🔄 Замыкание петель (Loop Closure)
    do_loop_closing: true                         # Включить замыкание петель
    loop_closure_enabled: true                    # Разрешить искать петли
    loop_closure_frequency: 1.0                   # Частота попыток замыкания петель (Гц)
    loop_closure_threshold: 4.0                   # Порог оценки совпадения сканов для петли
    loop_match_max_distance: 8.0                  # Макс. расстояние для поиска петли (м)
    loop_search_maximum_distance: 12.0            # Радиус поиска совпадений для петель
    loop_match_minimum_chain_size: 10             # Мин. количество совпадающих сканов в цепочке
    loop_match_maximum_variance_coverage: 0.2     # Допустимая дисперсия совпадений

    # 🔍 Расширенный линейный поиск сканов
    correlation_search_space_dimension: 3.0       # Размер поиска вокруг текущей позиции (м)
    correlation_search_space_resolution: 0.05     # Шаг линейного поиска (м)
    correlation_search_space_smear_deviation: 0.03 # Сглаживание в модели совпадения (м)

    # 🔄 Расширенный угловой поиск сканов
    angular_search_space_dimension: 6.2832        # Угловой диапазон поиска (рад) — 2π = 360°
    angular_search_space_resolution: 0.01745      # Шаг углового поиска (~1° в радианах)

    # ⚙️ Параметры расширенного сопоставления сканов
    use_response_expansion: true          # Расширять область поиска при неудаче
    match_window_size: 15                 # Размер окна сравнения
    match_search_size: 15                 # Размер области поиска
    match_response_threshold: 0.55        # Порог совпадения сканов
    minimum_score_threshold: 0.45         # Минимальный допуск совпадения

    # 🧠 Управление памятью
    max_submaps_to_keep: 20              # Количество подкарт, которые хранятся в графе

    # 💾 Сохранение карты
    serialization_time_interval: -1.0    # Отключить автосохранение (вручную через сервис)
Осталось запустить и построить карту:

ros2 launch slam_toolbox online_sync_launch.py slam_params_file:=~/ros2_ws/slam_param.yaml

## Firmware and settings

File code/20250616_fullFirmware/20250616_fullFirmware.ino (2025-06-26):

#include <WiFi.h>
#include <AsyncTCP.h>
#include <ESPAsyncWebServer.h>
#include <driver/uart.h>
#include "esp_task_wdt.h"
#include "driver/pcnt.h"
#include <math.h>
#include "driver/i2s.h"
#include <Adafruit_GFX.h>
#include <Adafruit_ST7735.h>
#include <SPI.h>

/* ---------- Wi-Fi ---------- */
constexpr char WIFI_SSID[] = "robotx";
constexpr char WIFI_PASS[] = "78914040";

/* ---------- Пины и параметры робота ---------- */
// Двигатели (H-мосты)
#define L_A 33
#define L_B 32
#define R_A 25
#define R_B 26

/* ── пины энкодеров ─────────────────────────────────────────*/
#define ENC_R_A 34
#define ENC_R_B 35
#define ENC_L_A 15
#define ENC_L_B 2

#define BAT ADC1_CHANNEL_3  //GPIO 39

#define BCLK_PIN 0
#define LRC_PIN 21
#define DATA_PIN 22

#define TFT_CS 5
#define TFT_DC 4
#define TFT_RST 27

Adafruit_ST7735 tft = Adafruit_ST7735(TFT_CS, TFT_DC, TFT_RST);

uint32_t bat_timer = 0;
int bat_check_time = 1000;
float voltage = 0;

const int IMG_WIDTH = 160;
const int IMG_HEIGHT = 128;
uint16_t buf[IMG_WIDTH * IMG_HEIGHT];

const int music_port = 12345;
const int image_port = 4210;

// Описание механики
constexpr float WHEEL_D = 0.044f;                                    // диаметр колеса, м
constexpr float BASE_L = 0.100f;                                     // база (расстояние между колёсами), м
constexpr int TICKS_REV = 2930;                                      // количество тиков энкодера на оборот колеса
constexpr float MM_PER_TICK = WHEEL_D * M_PI * 1000.0f / TICKS_REV;  // мм за один тик

/* ---------- Глобальные переменные состояния ---------- */
volatile uint8_t dutyLA = 0, dutyLB = 0, dutyRA = 0, dutyRB = 0;  // текущие ШИМ для H-мостов
volatile int32_t encTotL = 0, encTotR = 0;                        // накопленные тики энкодера
volatile int32_t prevEncL = 0, prevEncR = 0;
volatile float speedL = 0.0f, speedR = 0.0f;                   // измеренные скорости, мм/с
volatile float tgtL = 0.0f, tgtR = 0.0f;                       // целевые скорости, мм/с
volatile float odomX = 0.0f, odomY = 0.0f, odomTh = 0.0f;      // одометрия: положение робота (м, м, рад)
volatile float kp = 1.0f, ki = 0.8f, kd = 0.02f, kff = 0.25f;  // PID коэффициенты

volatile uint32_t lastCmdMs = 0;

// Режим выравнивания (для прямолинейного движения)
bool alignMode = false;
float alignSign = 1.0f;
int32_t alignRefL = 0, alignRefR = 0;
constexpr float kAlign = 1.0f;  // коэффициент P-контроллера выравнивания (мм -> мм/с)

/* ---------- Настройки лидара ---------- */
#define LIDAR_RX_PIN 17  // lidar TX -> ESP RX
#define LIDAR_TX_PIN 16  // lidar RX (не обязательно использовать)
#define LIDAR_BAUD 115200

static const uint8_t HDR[4] = { 0x55, 0xAA, 0x03, 0x08 };
static const uint8_t BODY_LEN = 32;      // байт в теле пакета лидара (8 точек по 4 байта)
static const uint8_t INTENSITY_MIN = 2;  // минимальное значение интенсивности для учёта точки
static const float MAX_SPREAD_DEG = 20.0;
#define FRAME_LEN 20   // длина упакованных данных на каждую порцию (2 байта нач.угол, 2 байта кон.угол, 8*2 байта дистанции)
#define MAX_FRAMES 64  // макс. количество порций на один полный оборот (64*20 ≈ 1280 байт)
static uint8_t scanBuf[MAX_FRAMES * FRAME_LEN];
static uint8_t *wr = scanBuf;
static uint8_t frameCount = 0;
static float prevStartAngle = -1;

/* ---------- Статистика ---------- */
volatile uint32_t stat_rx = 0;  // принятых 20-байтных пакетов от LDS
volatile uint32_t stat_tx = 0;  // переданных полных сканов по WS

/* ---------- Вспомогательные функции ---------- */
inline float decodeAngle(uint16_t raw) {
  // Декодирует угол (двухбайтное значение) из формата LDS
  float a = (raw - 0xA000) / 64.0f;
  if (a < 0) a += 360.0f;
  else if (a >= 360) a -= 360.0f;
  return a;
}
bool readBytes(HardwareSerial &serial, uint8_t *dst, size_t n, uint32_t timeout = 300) {
  uint32_t t0 = millis();
  for (size_t i = 0; i < n; ++i) {
    while (!serial.available()) {
      if (millis() - t0 > timeout) return false;
      vTaskDelay(1);
      esp_task_wdt_reset();
    }
    dst[i] = serial.read();
  }
  return true;
}
bool waitLidarHeader(HardwareSerial &serial) {
  uint8_t pos = 0;
  uint32_t t0 = millis();
  while (true) {
    if (serial.available()) {
      if (uint8_t(serial.read()) == HDR[pos]) {
        if (++pos == 4) return true;
      } else {
        pos = 0;
      }
    }
    if (millis() - t0 > 200) return false;
    esp_task_wdt_reset();
  }
}
inline uint16_t crc16(uint16_t crc, uint8_t v) {
  crc ^= v;
  for (uint8_t i = 0; i < 8; ++i) {
    crc = (crc & 1) ? (crc >> 1) ^ 0xA001 : (crc >> 1);
  }
  return crc;
}

/* ---------- Настройка WebSocket и HTTP ---------- */
AsyncWebServer server(80);
AsyncWebSocket ws("/ws");
AsyncWebSocketClient *wsClient = nullptr;
WiFiServer musicServer(music_port);
WiFiServer imageServer(image_port);
WiFiClient imageClient;
WiFiClient currentClient;

// Обработчик событий WebSocket
void onWsEvent(AsyncWebSocket *server, AsyncWebSocketClient *client,
               AwsEventType type, void *arg, uint8_t *data, size_t len) {
  if (type == WS_EVT_CONNECT) {
    // Новый клиент подключился
    if (wsClient && wsClient->status() == WS_CONNECTED) {
      // Закрываем предыдущего клиента, если был
      wsClient->close();
    }
    wsClient = client;
    //wsClient->printf("[WS] Connected (id=%u)\n", client->id());
    wsClient->client()->setNoDelay(true);  // отключаем алгоритм Нэгла для минимальной задержки
    Serial.printf("[WS] Client #%u connected\n", client->id());
  } else if (type == WS_EVT_DISCONNECT) {
    if (client == wsClient) {
      wsClient = nullptr;
      Serial.printf("[WS] Client #%u disconnected\n", client->id());
    }
  } else if (type == WS_EVT_DATA) {
    // NEW: входящее сообщение от клиента (ROS2), может содержать команду на движение
    AwsFrameInfo *info = (AwsFrameInfo *)arg;
    if (info->opcode == WS_BINARY && len == 4) {
      // Ожидаем 4-байтовое бинарное сообщение: [int16_t left_mm_s, int16_t right_mm_s]
      int16_t left = data[0] | (data[1] << 8);
      int16_t right = data[2] | (data[3] << 8);
      // Устанавливаем новые целевые скорости колес
      tgtL = (float)left;
      tgtR = (float)right;
      lastCmdMs = millis();  // ← обновили «пинг»
      // Включаем режим выравнивания, если |vL|≈|vR| и не ноль (робот едет прямо или крутится на месте)
      if (fabs(fabs(tgtL) - fabs(tgtR)) < 1.0f && fabs(tgtL) > 1.0f) {
        alignMode = true;
        alignSign = (tgtL * tgtR >= 0) ? 1.0f : -1.0f;
        alignRefL = encTotL;
        alignRefR = encTotR;
      } else {
        alignMode = false;
      }
      // Можно отправить подтверждение или лог (не обязательно)
      Serial.printf("[WS] Cmd: left=%d, right=%d\n", left, right);
    }
    // Если нужно обработать текстовые сообщения или другие бинарные команды, добавить тут
  }
}


void setup_i2s_streaming() {
  i2s_config_t i2s_config_tx = {
    .mode = static_cast<i2s_mode_t>(I2S_MODE_MASTER | I2S_MODE_TX),
    .sample_rate = 22050,
    .bits_per_sample = I2S_BITS_PER_SAMPLE_16BIT,
    .channel_format = I2S_CHANNEL_FMT_RIGHT_LEFT,
    .communication_format = I2S_COMM_FORMAT_I2S,
    .intr_alloc_flags = 0,
    .dma_buf_count = 8,
    .dma_buf_len = 512,
    .use_apll = false,
    .tx_desc_auto_clear = true,
    .fixed_mclk = 0
  };
  i2s_pin_config_t pin_config = {
    .bck_io_num = BCLK_PIN,
    .ws_io_num = LRC_PIN,
    .data_out_num = DATA_PIN,
    .data_in_num = I2S_PIN_NO_CHANGE
  };

  i2s_driver_install(I2S_NUM_0, &i2s_config_tx, 0, NULL);
  i2s_set_pin(I2S_NUM_0, &pin_config);
  i2s_zero_dma_buffer(I2S_NUM_0);
}

void setup_adc_bat() {
  adc1_config_width(ADC_WIDTH_BIT_12);
  adc1_config_channel_atten(BAT, ADC_ATTEN_DB_11);
}
float check_bat() {
  float voltage = 0;
  int i = 0;
  for (i = 0; i <= 10; i++) {
    int raw = adc1_get_raw(BAT);
    voltage += raw * 0.00235f;  // калибруйте под свою схему!
    delay(1);
  }
  return voltage / i;
}

void onImageReceived() {
  for (int y = 0; y < IMG_HEIGHT; y++) {
    for (int x = 0; x < IMG_WIDTH; x++) {
      uint16_t color = buf[y * IMG_WIDTH + x];
      //uint16_t pixel = (packetBuffer[i + 1] << 8) | packetBuffer[i];

      tft.drawPixel(x, y, color);
    }
  }
}

// Настройка HTTP-роутов
void setupRoutes() {
  server.on("/state", HTTP_GET, [](AsyncWebServerRequest *request) {
    // Формируем JSON с текущим состоянием робота
    char json[512];
    snprintf(json, sizeof(json),
             "{\"duty\":{\"L_A\":%u,\"L_B\":%u,\"R_A\":%u,\"R_B\":%u},"
             "\"enc\":{\"left\":%ld,\"right\":%ld},"
             "\"speed\":{\"left\":%.1f,\"right\":%.1f},"
             "\"target\":{\"left\":%.1f,\"right\":%.1f},"
             "\"odom\":{\"x\":%.3f,\"y\":%.3f,\"th\":%.3f}}",
             dutyLA, dutyLB, dutyRA, dutyRB,
             encTotL, encTotR,
             speedL, speedR, tgtL, tgtR,
             odomX, odomY, odomTh);
    request->send(200, "application/json", json);
  });
  server.on("/setSpeed", HTTP_GET, [](AsyncWebServerRequest *request) {
    if (request->hasParam("l")) tgtL = request->getParam("l")->value().toFloat();
    if (request->hasParam("r")) tgtR = request->getParam("r")->value().toFloat();
    lastCmdMs = millis();  // ← обновили «пинг»
    // Управление alignMode аналогично, как выше
    if (fabs(fabs(tgtL) - fabs(tgtR)) < 1.0f && fabs(tgtL) > 1.0f) {
      alignMode = true;
      alignSign = (tgtL * tgtR >= 0) ? 1.0f : -1.0f;
      alignRefL = encTotL;
      alignRefR = encTotR;
    } else {
      alignMode = false;
    }
    request->send(200, "text/plain", "ok");
  });
  server.on("/setCoeff", HTTP_GET, [](AsyncWebServerRequest *request) {
    if (request->hasParam("kp")) kp = request->getParam("kp")->value().toFloat();
    if (request->hasParam("ki")) ki = request->getParam("ki")->value().toFloat();
    if (request->hasParam("kd")) kd = request->getParam("kd")->value().toFloat();
    if (request->hasParam("kff")) kff = request->getParam("kff")->value().toFloat();
    request->send(200, "text/plain", "ok");
  });
  server.on("/resetEnc", HTTP_GET, [](AsyncWebServerRequest *request) {
    encTotL = encTotR = 0;
    prevEncL = prevEncR = 0;
    speedL = speedR = 0;
    alignMode = false;
    pcnt_counter_clear(PCNT_UNIT_0);
    pcnt_counter_clear(PCNT_UNIT_1);
    request->send(200, "text/plain", "enc reset");
  });
  server.on("/resetOdom", HTTP_GET, [](AsyncWebServerRequest *request) {
    odomX = odomY = odomTh = 0;
    request->send(200, "text/plain", "odom reset");
  });
  // Тестовая главная страница (необязательно)
  server.on("/", HTTP_GET, [](AsyncWebServerRequest *request) {
    request->send(200, "text/plain",
                  "Endpoints: /state /setSpeed /setCoeff /resetEnc /resetOdom");
  });
}

/* ---------- Управление моторами (PWM) ---------- */
inline void setPWM(uint8_t pin, uint8_t value) {
  analogWrite(pin, value);
  // Обновляем глобальные duty-переменные для мониторинга
  switch (pin) {
    case L_A: dutyLA = value; break;
    case L_B: dutyLB = value; break;
    case R_A: dutyRA = value; break;
    case R_B: dutyRB = value; break;
  }
}
inline void stopMotors() {
  setPWM(L_A, 0);
  setPWM(L_B, 0);
  setPWM(R_A, 0);
  setPWM(R_B, 0);
}

/* ---------- Инициализация счетчиков PCNT ---------- */
void pcntInit(pcnt_unit_t unit, gpio_num_t pulse_pin, gpio_num_t ctrl_pin) {
  pcnt_config_t cfg = {};
  cfg.unit = unit;
  cfg.channel = PCNT_CHANNEL_0;
  cfg.pulse_gpio_num = pulse_pin;
  cfg.ctrl_gpio_num = ctrl_pin;
  cfg.pos_mode = PCNT_COUNT_INC;
  cfg.neg_mode = PCNT_COUNT_DEC;
  cfg.lctrl_mode = PCNT_MODE_REVERSE;
  cfg.hctrl_mode = PCNT_MODE_KEEP;
  cfg.counter_h_lim = 32767;
  cfg.counter_l_lim = -32768;
  pcnt_unit_config(&cfg);
  pcnt_set_filter_value(unit, 100);
  pcnt_filter_enable(unit);
  pcnt_counter_clear(unit);
  pcnt_counter_resume(unit);
}
inline int16_t readEncoder(pcnt_unit_t unit) {
  int16_t count = 0;
  pcnt_get_counter_value(unit, &count);
  pcnt_counter_clear(unit);
  return count;
}

/* ---------- PID-регулятор скорости ---------- */
void updatePID() {
  static uint32_t prevMillis = millis();
  static float iTermL = 0, iTermR = 0;
  static float prevErrorL = 0, prevErrorR = 0;
  static float lastTgtL = 0, lastTgtR = 0;

  uint32_t now = millis();
  float dt = (now - prevMillis) * 0.001f;
  if (dt < 0.001f) dt = 0.001f;
  prevMillis = now;

  // Сброс интегральной части при изменении целевой скорости или переходе через 0
  if (tgtL != lastTgtL || fabs(tgtL) < 1.0f) {
    iTermL = 0;
    prevErrorL = 0;
  }
  if (tgtR != lastTgtR || fabs(tgtR) < 1.0f) {
    iTermR = 0;
    prevErrorR = 0;
  }
  lastTgtL = tgtL;
  lastTgtR = tgtR;

  // Выравнивание (P-регулятор) – корректирует цель при езде строго прямо или повороте на месте
  float corr = 0.0f;
  if (alignMode) {
    int32_t dL = encTotL - alignRefL;
    int32_t dR = encTotR - alignRefR;
    float diff_mm = (float)(dL - alignSign * dR) * MM_PER_TICK;  // разница пройденного пути (мм)
    corr = kAlign * diff_mm;                                     // мм/с коррекция
  }
  float tgtCorrL = tgtL - corr;
  float tgtCorrR = tgtR + alignSign * corr;

  // PID для левого и правого колеса
  float errorL = tgtCorrL - speedL;
  float errorR = tgtCorrR - speedR;
  iTermL += errorL * dt;
  iTermR += errorR * dt;
  // ограничиваем накопление интегральной ошибки
  const float I_LIMIT = 300.0f;
  if (iTermL > I_LIMIT) iTermL = I_LIMIT;
  if (iTermL < -I_LIMIT) iTermL = -I_LIMIT;
  if (iTermR > I_LIMIT) iTermR = I_LIMIT;
  if (iTermR < -I_LIMIT) iTermR = -I_LIMIT;
  float dTermL = (errorL - prevErrorL) / dt;
  float dTermR = (errorR - prevErrorR) / dt;
  prevErrorL = errorL;
  prevErrorR = errorR;
  // Управляющее воздействие
  float outputL = kp * errorL + ki * iTermL + kd * dTermL + kff * tgtCorrL;
  float outputR = kp * errorR + ki * iTermR + kd * dTermR + kff * tgtCorrR;
  // Ограничиваем PWM
  if (outputL > 255) outputL = 255;
  if (outputL < -255) outputL = -255;
  if (outputR > 255) outputR = 255;
  if (outputR < -255) outputR = -255;
  // Задаём PWM на моторах (A-вперёд, B-назад)
  uint8_t pwmLA, pwmLB, pwmRA, pwmRB;
  if (outputL >= 0) {
    pwmLA = (uint8_t)outputL;
    pwmLB = 0;
  } else {
    pwmLA = 0;
    pwmLB = (uint8_t)(-outputL);
  }
  if (outputR >= 0) {
    pwmRA = (uint8_t)outputR;
    pwmRB = 0;
  } else {
    pwmRA = 0;
    pwmRB = (uint8_t)(-outputR);
  }
  setPWM(L_A, pwmLA);
  setPWM(L_B, pwmLB);
  setPWM(R_A, pwmRA);
  setPWM(R_B, pwmRB);
}

/* ---------- Задача чтения Лидара (поток на Core 1) ---------- */
void lidarTask(void *param) {
  esp_task_wdt_add(NULL);
  Serial2.begin(LIDAR_BAUD, SERIAL_8N1, LIDAR_RX_PIN, LIDAR_TX_PIN);
  uint8_t body[BODY_LEN];
  while (true) {
    esp_task_wdt_reset();
    vTaskDelay(1);
    if (!waitLidarHeader(Serial2)) {
      continue;
    }
    if (!readBytes(Serial2, body, BODY_LEN)) {
      continue;
    }
    // Распарсить порцию точек лидара
    float startDeg = decodeAngle(body[2] | (body[3] << 8));
    uint8_t offset = 4;
    uint16_t dist[8];
    uint8_t quality[8];
    for (int i = 0; i < 8; ++i) {
      dist[i] = body[offset] | (body[offset + 1] << 8);
      quality[i] = body[offset + 2];
      offset += 3;
    }
    float endDeg = decodeAngle(body[offset] | (body[offset + 1] << 8));
    if (endDeg < startDeg) endDeg += 360.0f;
    if (endDeg - startDeg > MAX_SPREAD_DEG) {
      // Пропускаем пакет, если слишком большой разрыв (ошибка)
      continue;
    }
    // Упаковываем 20 байт в общий буфер скана
    uint16_t s = (uint16_t)(startDeg * 100 + 0.5f);
    uint16_t e = (uint16_t)(endDeg * 100 + 0.5f);
    *wr++ = s & 0xFF;
    *wr++ = s >> 8;
    *wr++ = e & 0xFF;
    *wr++ = e >> 8;
    for (int i = 0; i < 8; ++i) {
      uint16_t d = (quality[i] >= INTENSITY_MIN) ? dist[i] : 0;
      *wr++ = d & 0xFF;
      *wr++ = d >> 8;
    }
    frameCount++;
    stat_rx++;
    if (frameCount >= MAX_FRAMES) {
      frameCount = 0;
      wr = scanBuf;
      prevStartAngle = -1;  // сброс для корректного «перескока» угла
      continue;             // переходим к следующему пакету
    }
    // Проверяем перескок через 0° (начало нового круга)
    if (prevStartAngle >= 0.0f && startDeg < prevStartAngle && frameCount >= 30) {
      size_t scanSize = frameCount * FRAME_LEN;
      // Вычисляем CRC для всего скана
      uint16_t crc = 0xFFFF;
      for (size_t i = 0; i < scanSize; ++i) {
        crc = crc16(crc, scanBuf[i]);
      }
      scanBuf[scanSize] = crc & 0xFF;
      scanBuf[scanSize + 1] = crc >> 8;
      // Отправляем по WebSocket, если клиент подключен
      if (wsClient && wsClient->canSend()) {
        wsClient->binary(scanBuf, scanSize + 2);
        stat_tx++;
      }
      // Сбрасываем буфер для следующего оборота
      wr = scanBuf;
      frameCount = 0;
    }
    prevStartAngle = startDeg;
  }
}

/* ---------- SETUP ---------- */
void setup() {
  Serial.begin(115200);
  Serial.println("=== ESP32 Lidar+Motor Bridge ===");
  setup_i2s_streaming();  // Для музыки
  setup_adc_bat();        // Для чтения BAT

  tft.initR(INITR_BLACKTAB);
  tft.setRotation(1);
  tft.fillScreen(ST77XX_BLACK);
  // Wi-Fi подключение
  WiFi.mode(WIFI_STA);
  WiFi.setSleep(false);
  WiFi.begin(WIFI_SSID, WIFI_PASS);
  while (WiFi.status() != WL_CONNECTED) {
    delay(300);
    Serial.print('.');
  }
  Serial.printf("\nWiFi connected, IP: %s\n", WiFi.localIP().toString().c_str());
  // Настройка GPIO
  pinMode(L_A, OUTPUT);
  pinMode(L_B, OUTPUT);
  pinMode(R_A, OUTPUT);
  pinMode(R_B, OUTPUT);
  stopMotors();
  // PCNT для энкодеров
  pcntInit(PCNT_UNIT_0, (gpio_num_t)ENC_R_A, (gpio_num_t)ENC_R_B);
  pcntInit(PCNT_UNIT_1, (gpio_num_t)ENC_L_A, (gpio_num_t)ENC_L_B);
  // Запуск веб-сервера и WebSocket
  ws.onEvent(onWsEvent);
  server.addHandler(&ws);
  setupRoutes();
  server.begin();
  musicServer.begin();
  imageServer.begin();
  // Запуск задачи лидара на ядре 0
  xTaskCreatePinnedToCore(lidarTask, "LidarTask", 4096, nullptr, 2, nullptr, 0);
}

/* ---------- LOOP ---------- */
void loop() {
  static uint32_t t10 = 0, t20 = 0, t2000 = 0;
  uint32_t now = millis();
  /* --- safety timeout: если 3000 ms нет команд, стоп --- */
  if (now - lastCmdMs > 3000) {
    if (tgtL != 0 || tgtR != 0) {  // меняем только один раз
      tgtL = tgtR = 0;
      alignMode = false;
      // мгновенно убираем PWM – чтобы робот тут же замер
      stopMotors();
      Serial.println("[SAFE] cmd timeout → STOP");
    }
  }
  // Каждые 10 мс: считываем энкодеры, обновляем одометрию
  if (now - t10 >= 10) {
    t10 = now;
    int16_t dR = readEncoder(PCNT_UNIT_0);
    int16_t dL = readEncoder(PCNT_UNIT_1);
    encTotR += dR;
    encTotL += dL;
    // Расстояние, пройденное каждым колесом за 10 мс (в метрах)
    float sR = dR * MM_PER_TICK / 1000.0f;
    float sL = dL * MM_PER_TICK / 1000.0f;
    // Обновляем одометрические координаты (в глобальной системе odom)
    float ds = 0.5f * (sR + sL);
    float dth = (sR - sL) / BASE_L;
    float midTh = odomTh + 0.5f * dth;
    odomX += ds * cosf(midTh);
    odomY += ds * sinf(midTh);
    odomTh += dth;
    // Нормализуем угол odomTh в [-pi, pi]
    if (odomTh > M_PI) odomTh -= 2 * M_PI;
    if (odomTh < -M_PI) odomTh += 2 * M_PI;
  }
  // Каждые 20 мс: вычисляем текущие скорости колес (мм/с)
  if (now - t20 >= 20) {
    float dt = (now - t20) * 0.001f;
    t20 = now;
    speedL = (encTotL - prevEncL) * MM_PER_TICK / dt;
    speedR = (encTotR - prevEncR) * MM_PER_TICK / dt;
    prevEncL = encTotL;
    prevEncR = encTotR;
  }
  // Каждые 20 мс: обновляем PID-регулятор и ШИМ моторов
  static uint32_t tPID = 0;
  if (now - tPID >= 20) {
    tPID = now;
    updatePID();
  }
  // Обслуживание клиентов WebSocket (освобождение памяти для отключившихся)
  ws.cleanupClients();
  // Каждые 2 с: выводим IP (для мониторинга, не обязательно)
  if (now - t2000 >= 2000) {
    t2000 = now;
    Serial.println(WiFi.localIP());
  }


  /*

  WiFiClient client = musicServer.available();
  if (client) {
    Serial.println("TCP client connected.");
    uint8_t buffer[1024];
    while (client.connected()) {
      int n = client.read(buffer, sizeof(buffer));
      if (n > 0) {
        Serial.print("Received TCP audio bytes: ");
        Serial.println(n);
        // Debug: print first few bytes
        for (int i = 0; i < n && i < 8; ++i) {
          Serial.print(buffer[i], HEX);
          Serial.print(" ");
        }
        Serial.println();
        size_t bytes_written;
        i2s_write(I2S_NUM_0, buffer, n, &bytes_written, portMAX_DELAY);
      }
      delay(1);
    }
    client.stop();
    Serial.println("TCP client disconnected.");
  }
*/
  if (!currentClient || !currentClient.connected()) {
    currentClient = musicServer.available();
    if (currentClient) {
      Serial.println("TCP client connected.");
    }
  }

  if (currentClient && currentClient.connected()) {
    uint8_t buffer[1024];
    int n = currentClient.read(buffer, sizeof(buffer));
    if (n > 0) {
      Serial.print("Received TCP audio bytes: ");
      Serial.println(n);
      for (int i = 0; i < n && i < 8; ++i) {
        Serial.print(buffer[i], HEX);
        Serial.print(" ");
      }
      Serial.println();

      size_t bytes_written;
      i2s_write(I2S_NUM_0, buffer, n, &bytes_written, 0);  // Non-blocking
    }
  } else if (currentClient) {
    Serial.println("TCP client disconnected.");
    currentClient.stop();
  }


  imageClient = imageServer.available();
  if (imageClient) {
    Serial.println("✅ Client connected");
    int total = 0;
    uint8_t *byte_buf = (uint8_t *)buf;
    int size = IMG_WIDTH * IMG_HEIGHT * 2;

    while (total < size) {
      if (imageClient.available()) {
        int r = imageClient.read(byte_buf + total, size - total);
        if (r > 0) total += r;
      }
    }

    Serial.println("✅ Image fully received!");
    onImageReceived();
    imageClient.stop();
  }
}

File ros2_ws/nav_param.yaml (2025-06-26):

bt_navigator:
  ros__parameters:
    global_frame: map
    robot_base_frame: base_link
    odom_topic: /odom
    bt_loop_duration: 10
    default_server_timeout: 20
    wait_for_service_timeout: 1000
    action_server_result_timeout: 900.0
    navigators: ["navigate_to_pose", "navigate_through_poses"]
    navigate_to_pose:
      plugin: "nav2_bt_navigator::NavigateToPoseNavigator"
    navigate_through_poses:
      plugin: "nav2_bt_navigator::NavigateThroughPosesNavigator"
    # 'default_nav_through_poses_bt_xml' and 'default_nav_to_pose_bt_xml' are use defaults:
    # nav2_bt_navigator/navigate_to_pose_w_replanning_and_recovery.xml
    # nav2_bt_navigator/navigate_through_poses_w_replanning_and_recovery.xml
    # They can be set here or via a RewrittenYaml remap from a parent launch file to Nav2.

    # plugin_lib_names is used to add custom BT plugins to the executor (vector of strings).
    # Built-in plugins are added automatically
    # plugin_lib_names: []

    error_code_names:
      - compute_path_error_code
      - follow_path_error_code

controller_server:
  ros__parameters:
    controller_plugins: ["FollowPath"]
    
    FollowPath:
      plugin: "nav2_regulated_pure_pursuit_controller::RegulatedPurePursuitController"
      lookahead_dist:           0.15         # меньше → «морковка» ближе и почти спереди
      use_path_orientations:    false        # берём угол на «морковку», а не из Path
      use_rotate_to_heading:    false        # запрещаем отдельный pivot-разворот

      # --- скорость ---
      desired_linear_vel:       0.1         # м/с
      max_robot_angular_vel:    1.8          # рад/с
      max_angular_accel:        2.0          # рад/с²
      regulate_turning_velocity: true
      


local_costmap:
  local_costmap:
    ros__parameters:
      update_frequency: 5.0
      publish_frequency: 2.0
      global_frame: odom
      robot_base_frame: base_link
      rolling_window: true
      width: 3
      height: 3
      resolution: 0.05
      #robot_radius: 0.06
      footprint: "[[0.05, 0.05], [0.05, -0.05], [-0.05, -0.05], [-0.05, 0.05]]"
      footprint_padding: 0.01
      plugins: ["voxel_layer", "inflation_layer"]
      inflation_layer:
        plugin: "nav2_costmap_2d::InflationLayer"
        cost_scaling_factor: 10.0
        inflation_radius: 0.2
      voxel_layer:
        plugin: "nav2_costmap_2d::VoxelLayer"
        enabled: True
        publish_voxel_map: True
        origin_z: 0.0
        z_resolution: 0.05
        z_voxels: 16
        max_obstacle_height: 2.0
        mark_threshold: 0
        observation_sources: scan
        scan:
          topic: /scan
          max_obstacle_height: 2.0
          clearing: True
          marking: True
          data_type: "LaserScan"
          raytrace_max_range: 3.0
          raytrace_min_range: 0.0
          obstacle_max_range: 2.5
          obstacle_min_range: 0.0
      static_layer:
        plugin: "nav2_costmap_2d::StaticLayer"
        map_subscribe_transient_local: True
      always_send_full_costmap: True

global_costmap:
  global_costmap:
    ros__parameters:
      update_frequency: 1.0
      publish_frequency: 1.0
      global_frame: map
      robot_base_frame: base_link
      #robot_radius: 0.06
      footprint: "[[0.05, 0.05], [0.05, -0.05], [-0.05, -0.05], [-0.05, 0.05]]"
      footprint_padding: 0.01
      resolution: 0.05
      track_unknown_space: true
      plugins: ["static_layer", "obstacle_layer", "inflation_layer"]
      obstacle_layer:
        plugin: "nav2_costmap_2d::ObstacleLayer"
        enabled: True
        observation_sources: scan
        scan:
          topic: /scan
          max_obstacle_height: 2.0
          clearing: True
          marking: True
          data_type: "LaserScan"
          raytrace_max_range: 3.0
          raytrace_min_range: 0.0
          obstacle_max_range: 2.5
          obstacle_min_range: 0.0
      static_layer:
        plugin: "nav2_costmap_2d::StaticLayer"
        map_subscribe_transient_local: True
      inflation_layer:
        plugin: "nav2_costmap_2d::InflationLayer"
        cost_scaling_factor: 10.0
        inflation_radius: 0.2
      always_send_full_costmap: True

# The yaml_filename does not need to be specified since it going to be set by defaults in launch.
# If you'd rather set it in the yaml, remove the default "map" value in the tb3_simulation_launch.py
# file & provide full path to map below. If CLI map configuration or launch default is provided, that will be used.
# map_server:
#   ros__parameters:
#     yaml_filename: ""

map_saver:
  ros__parameters:
    save_map_timeout: 5.0
    free_thresh_default: 0.25
    occupied_thresh_default: 0.65
    map_subscribe_transient_local: True

planner_server:
  ros__parameters:
    expected_planner_frequency: 20.0
    planner_plugins: ["GridBased"]
    costmap_update_timeout: 1.0
    GridBased:
      plugin: "nav2_navfn_planner::NavfnPlanner"
      tolerance: 0.05
      use_astar: false
      allow_unknown: true
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

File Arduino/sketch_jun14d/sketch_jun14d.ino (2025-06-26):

/****************************************************************
 *  ESP32  –  Twist-PID + Encoder-Alignment
 *
 *  • КОМАНДНЫЙ СЛОЙ
 *    /setSpeed?l=&r=      – целевые скорости колёс, мм/с
 *    /setCoeff?kp&ki&kd&kff=
 *    /state               – полное состояние (duty, enc, speed, target, odom)
 *    /resetEnc /resetOdom
 *
 *  • ДВИГАТЕЛИ
 *    GPIO 33/32  – левый H-мост   (A-канал = вперёд)
 *    GPIO 26/25  – правый H-мост
 *
 *  • СЧЁТЧИКИ PCNT
 *    UNIT0 = 18 (A) / 19 (B)  – правый энкодер
 *    UNIT1 = 34 (A) / 35 (B)  – левый  энкодер
 *
 *  • ОДОМЕТРИЯ
 *    Ø 44 мм, база 96 мм, 2930 тиков / оборот
 *
 *  • PID
 *    kp/ki/kd – обычный PID c feed-forward kff
 *    P-контур "прямо" (`kAlign`) — сравнивает абсолютный ход левого и правого
 *    колеса и корректирует target, если робот должен ехать строго прямо
 *    (или крутиться на месте)
 ****************************************************************/

#include <WiFi.h>
#include <WiFiServer.h>
#include <ESPAsyncWebServer.h>
#include <AsyncTCP.h>
#include "driver/pcnt.h"
#include <math.h>
#include "driver/i2s.h"
#include <Adafruit_GFX.h>
#include <Adafruit_ST7735.h>
#include <SPI.h>

#define L_A 33
#define L_B 32
#define R_A 25
#define R_B 26
#define ENC_R_A 34
#define ENC_R_B 35
#define ENC_L_A 15
#define ENC_L_B 2

#define BAT ADC1_CHANNEL_3  //GPIO 39

#define BCLK_PIN 0
#define LRC_PIN 21
#define DATA_PIN 22

#define TFT_CS 5
#define TFT_DC 4
#define TFT_RST 27

uint32_t bat_timer = 0;
int bat_check_time = 1000;
float voltage = 0;

const int IMG_WIDTH = 160;
const int IMG_HEIGHT = 128;
uint16_t buf[IMG_WIDTH * IMG_HEIGHT];


/* ────── Wi-Fi ───── */
constexpr char SSID[] = "robotx";
constexpr char PASS[] = "78914040";
const int music_port = 12345;
const int image_port = 4210;

/* ────── mechanics ───── */
constexpr float WHEEL_D = 0.044f;  // m
constexpr float BASE_L = 0.096f;   // m
constexpr int TICKS_REV = 2930;
constexpr float MM_PER_TICK = WHEEL_D * M_PI * 1000.0f / TICKS_REV;

volatile uint8_t dutyLA, dutyLB, dutyRA, dutyRB;
volatile int32_t encTotL = 0, encTotR = 0, prevEncL = 0, prevEncR = 0;
volatile float speedL = 0, speedR = 0, tgtL = 0, tgtR = 0;
volatile float odomX = 0, odomY = 0, odomTh = 0;
volatile float kp = 2.0f, ki = 3.5f, kd = 0.01f, kff = 0.75f;

bool alignMode = false;  // включён ли «режим прямо»
float alignSign = 1;     //  +1 прямой ход, −1 разворот
int32_t alignRefL = 0, alignRefR = 0;
constexpr float kAlign = 1;  // (мм ⇒ мм/с)

inline void pwm(uint8_t pin, uint8_t d) {
  analogWrite(pin, d);
  switch (pin) {
    case L_A: dutyLA = d; break;
    case L_B: dutyLB = d; break;
    case R_A: dutyRA = d; break;
    case R_B: dutyRB = d; break;
  }
}
inline void stopMotors() {
  pwm(L_A, 0);
  pwm(L_B, 0);
  pwm(R_A, 0);
  pwm(R_B, 0);
}

inline void pcntInit(pcnt_unit_t u, gpio_num_t a, gpio_num_t b) {
  pcnt_config_t c{};
  c.unit = u;
  c.channel = PCNT_CHANNEL_0;
  c.pulse_gpio_num = a;
  c.ctrl_gpio_num = b;
  c.pos_mode = PCNT_COUNT_INC;
  c.neg_mode = PCNT_COUNT_DEC;
  c.lctrl_mode = PCNT_MODE_REVERSE;
  c.hctrl_mode = PCNT_MODE_KEEP;
  c.counter_h_lim = 32767;
  c.counter_l_lim = -32768;
  pcnt_unit_config(&c);
  pcnt_set_filter_value(u, 100);
  pcnt_filter_enable(u);
  pcnt_counter_clear(u);
  pcnt_counter_resume(u);
}
inline int16_t snap(pcnt_unit_t u) {
  int16_t v;
  pcnt_get_counter_value(u, &v);
  pcnt_counter_clear(u);
  return v;
}

/* ────── API ───── */
AsyncWebServer server(80);
WiFiServer musicServer(music_port);
WiFiServer imageServer(image_port);
WiFiClient imageClient;


Adafruit_ST7735 tft = Adafruit_ST7735(TFT_CS, TFT_DC, TFT_RST);
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
